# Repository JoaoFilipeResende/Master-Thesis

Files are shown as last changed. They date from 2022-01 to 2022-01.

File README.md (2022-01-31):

# Master Thesis Project
## Autonomous High-Resolution Image Acquisition System for Plankton

<p align="center">

</p>

### System Architecture

<p align="center">
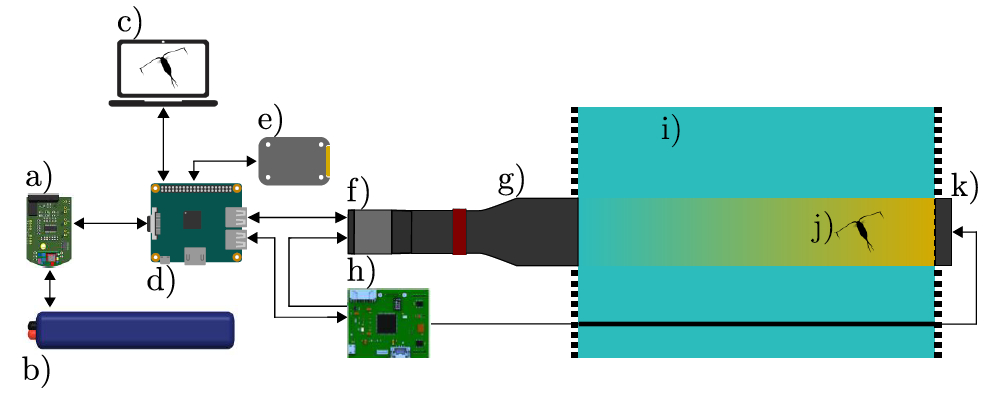
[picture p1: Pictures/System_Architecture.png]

</p>

a) BMS; b) Battery; c) External Connection; d) SBC; e) Storage; f) Camera; g) Optical lens; h) Illumination system control board; i) Water Column; j) Organism; k) LEDs.
   
### Mechanical Structure

<p align="center">
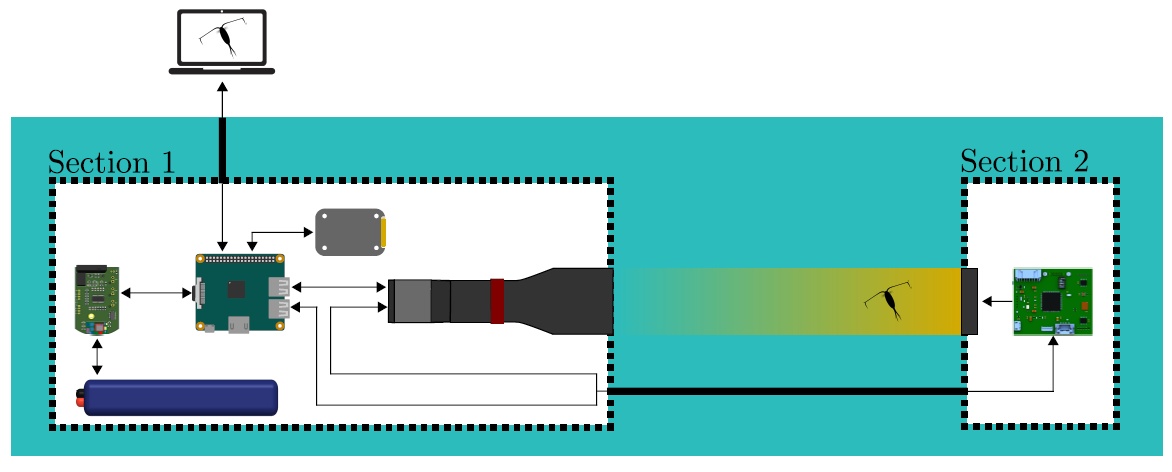
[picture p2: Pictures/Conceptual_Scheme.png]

</p>

### Hardware

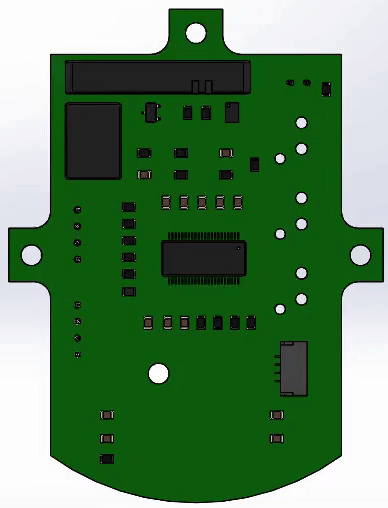
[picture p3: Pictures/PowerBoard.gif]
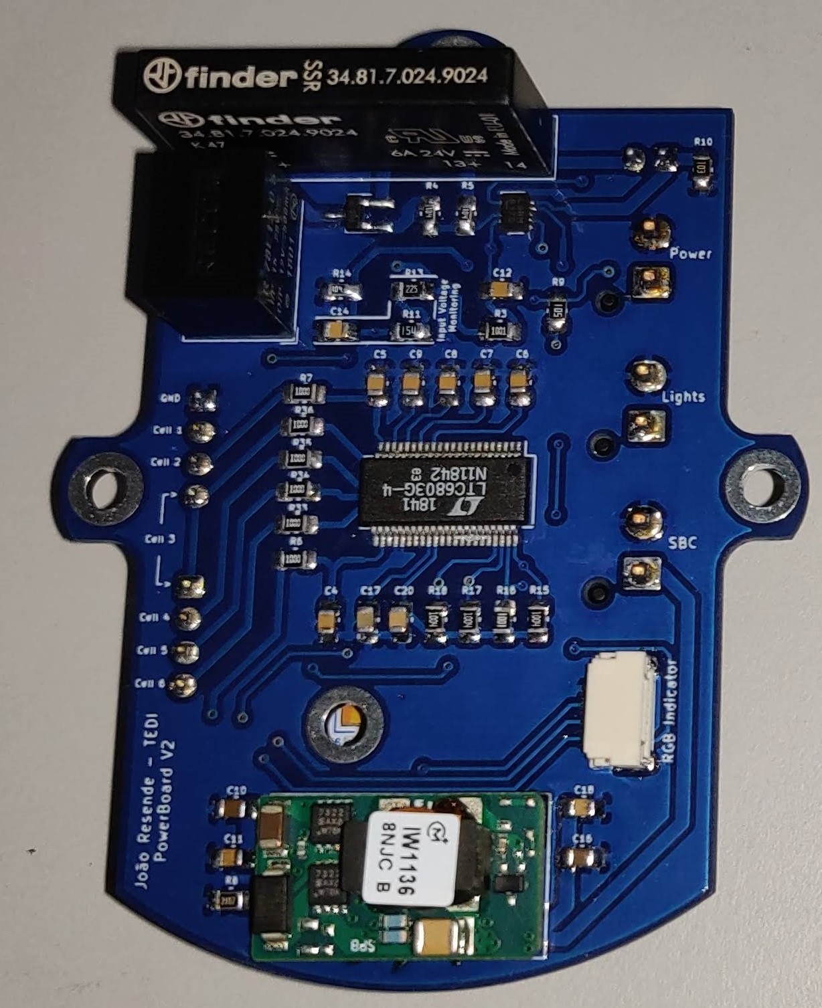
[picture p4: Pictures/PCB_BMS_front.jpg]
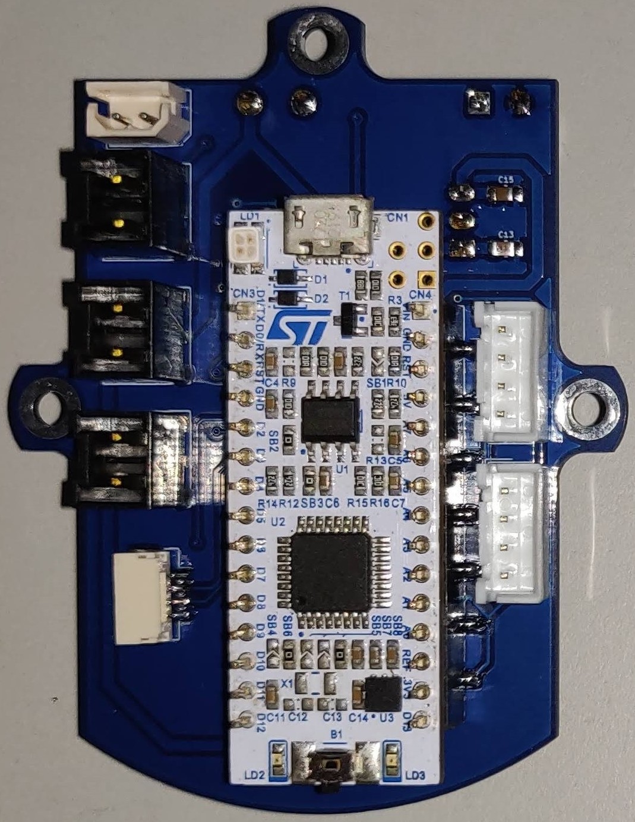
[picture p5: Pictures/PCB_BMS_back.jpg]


### Software

### Experimental Results

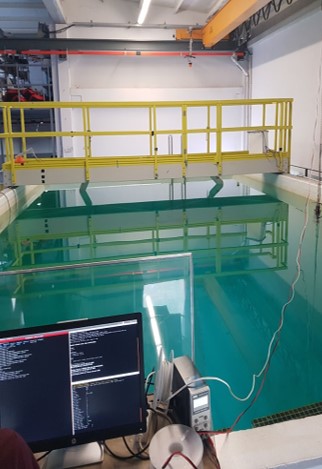
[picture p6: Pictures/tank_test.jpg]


<p align="center">
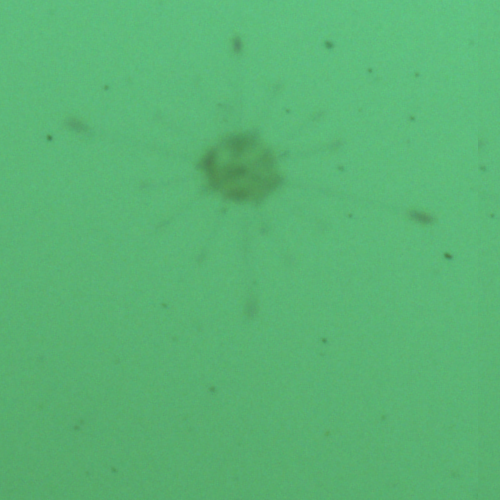
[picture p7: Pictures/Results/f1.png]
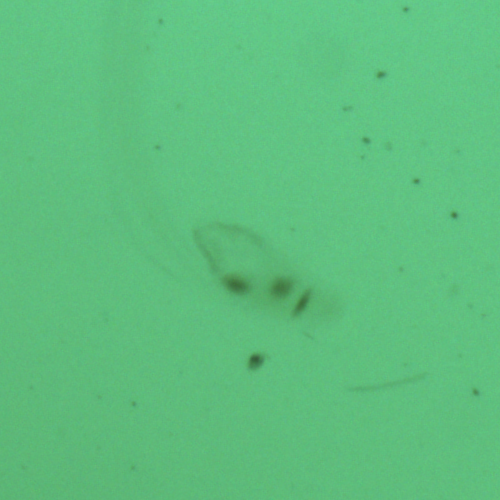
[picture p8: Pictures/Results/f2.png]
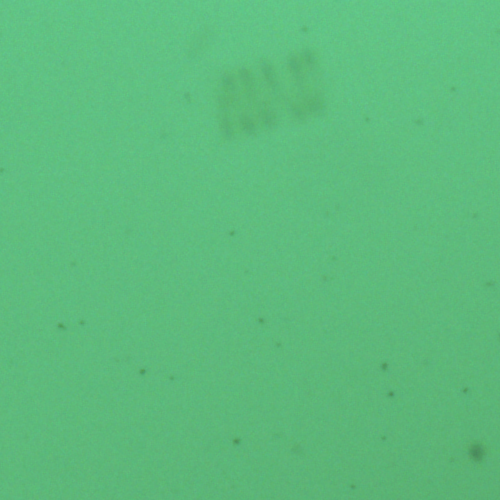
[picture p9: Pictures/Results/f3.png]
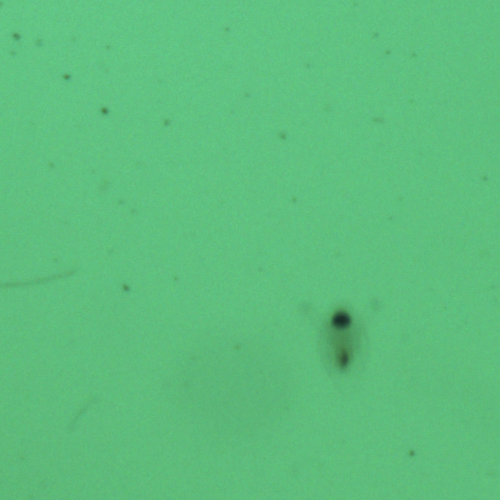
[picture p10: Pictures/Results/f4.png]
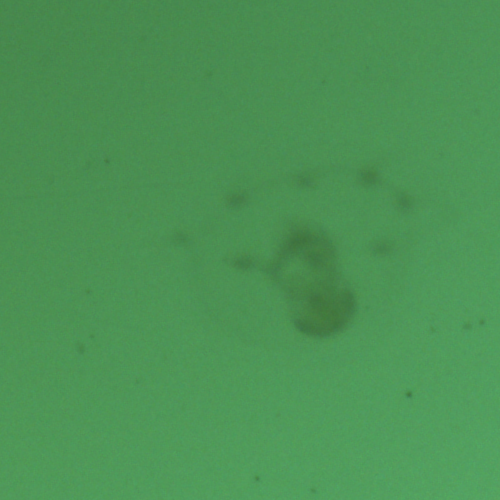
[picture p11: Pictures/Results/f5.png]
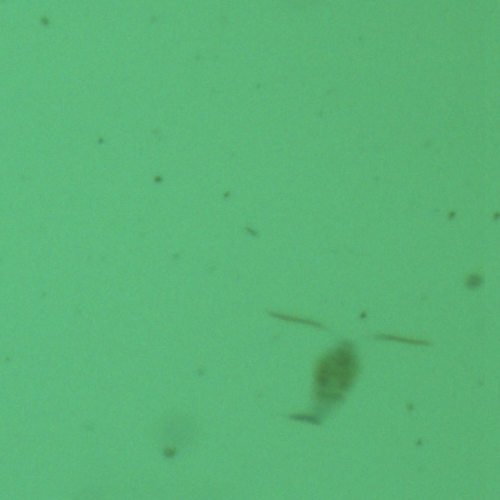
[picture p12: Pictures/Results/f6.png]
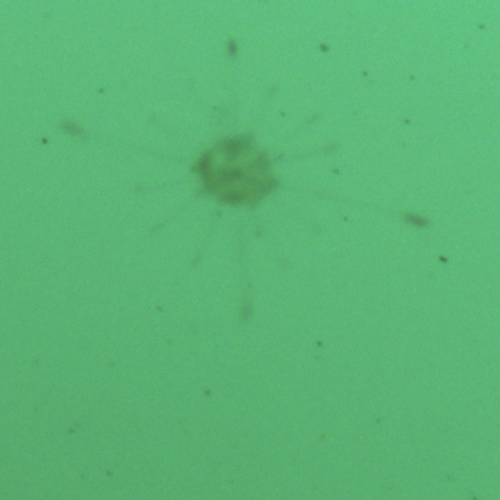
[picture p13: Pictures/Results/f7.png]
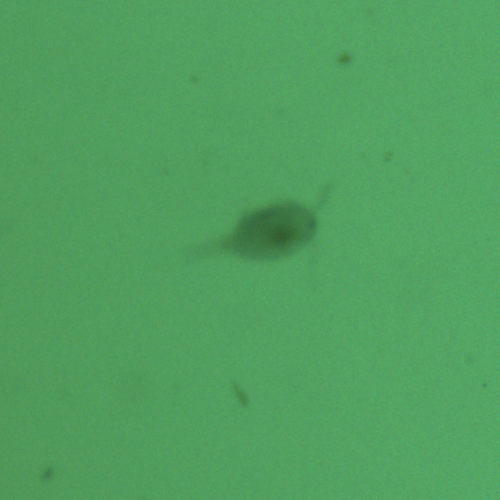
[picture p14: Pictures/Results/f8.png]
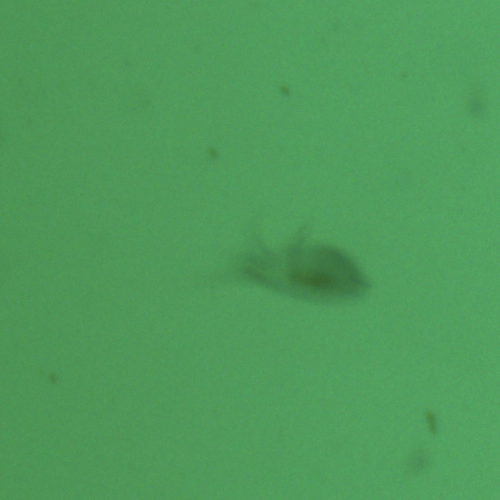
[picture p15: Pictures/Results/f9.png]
         
 </p>

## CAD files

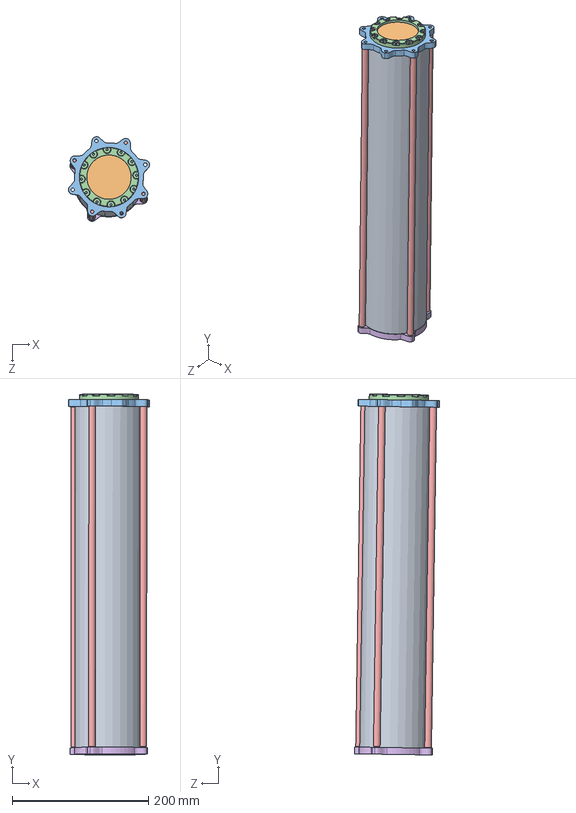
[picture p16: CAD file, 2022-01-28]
Mechanical Parts/assembly_camara.SLDASM
119.1 x 529.5 x 124.3 mm
cilider_camara
glass_camara_light
tampa_front1_camara_light
tampa_front2_camara_light
vara_suporte_camara x 4
tampa_back_camara

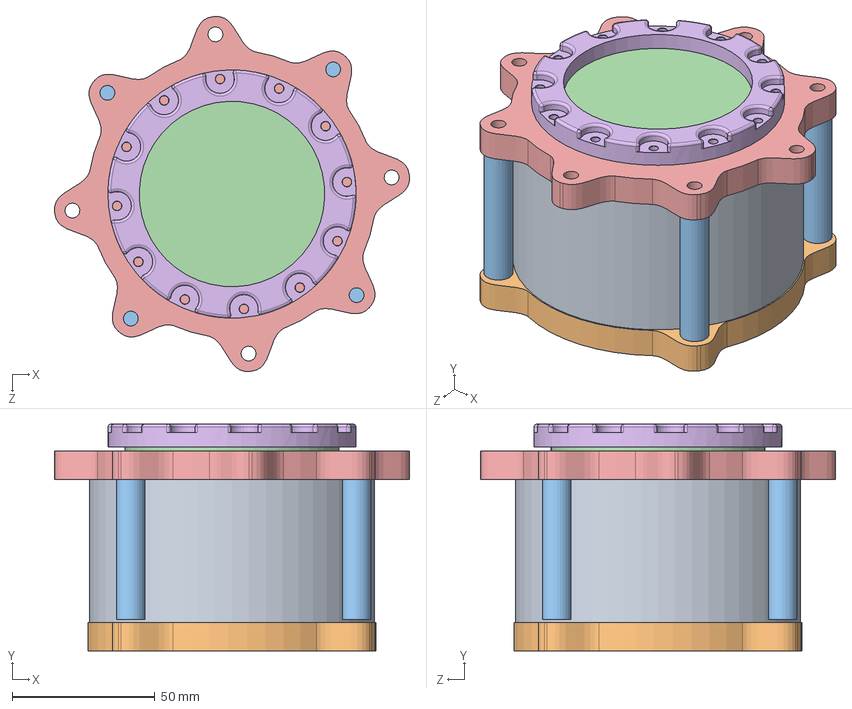
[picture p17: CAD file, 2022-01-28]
Mechanical Parts/assembly_light.SLDASM
124.4 x 79.5 x 124.4 mm
cilider_light
tampa_back_light
vara_suporte_light x 4
glass_camara_light
tampa_front1_camara_light
tampa_front2_camara_light

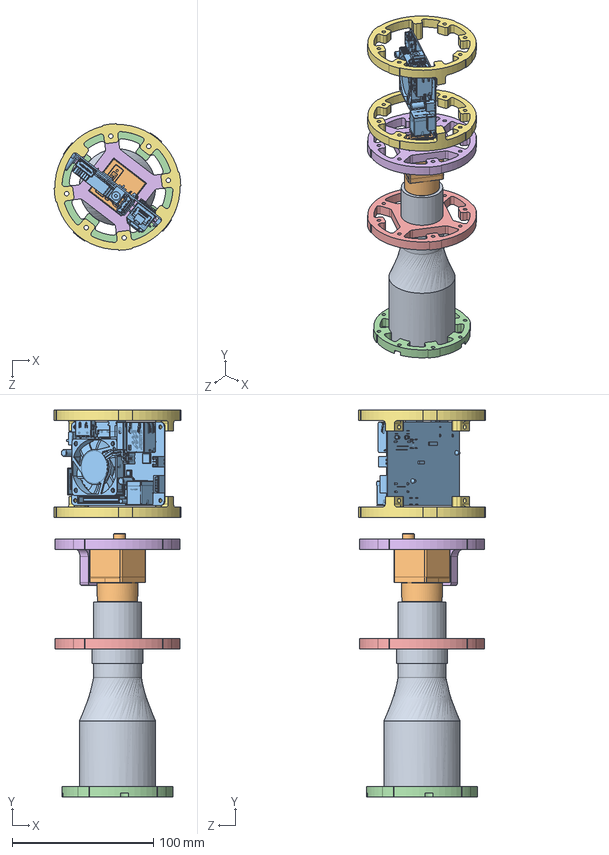
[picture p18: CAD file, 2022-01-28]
Mechanical Parts/assembly_internal.SLDASM
89.6 x 273.6 x 89.6 mm
DTCM230-36
IDS
Odroid-XU4
suporte_lente_meio
meio
camara
odroid x 2

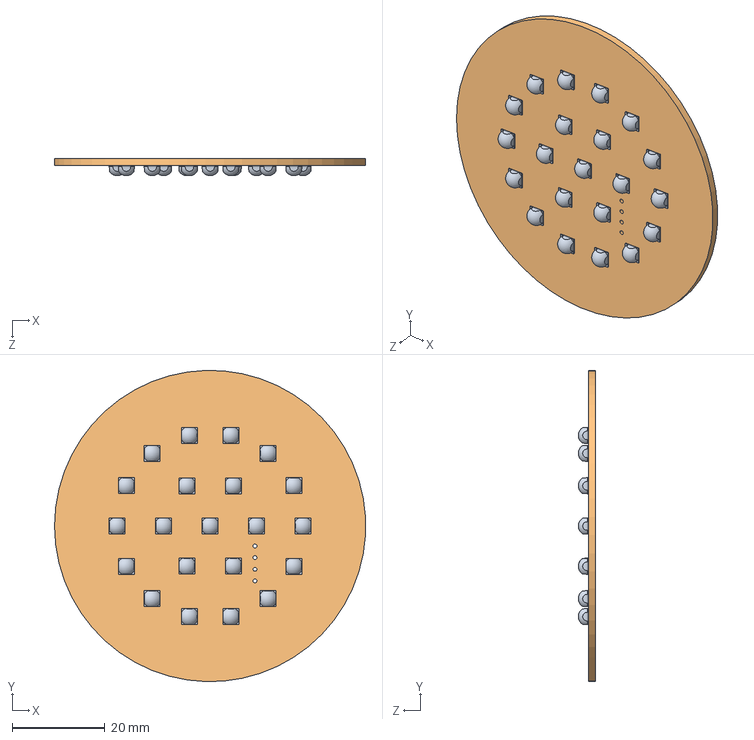
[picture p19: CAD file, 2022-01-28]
Mechanical Parts/Ligths.SLDASM
66.9 x 67.0 x 3.75 mm

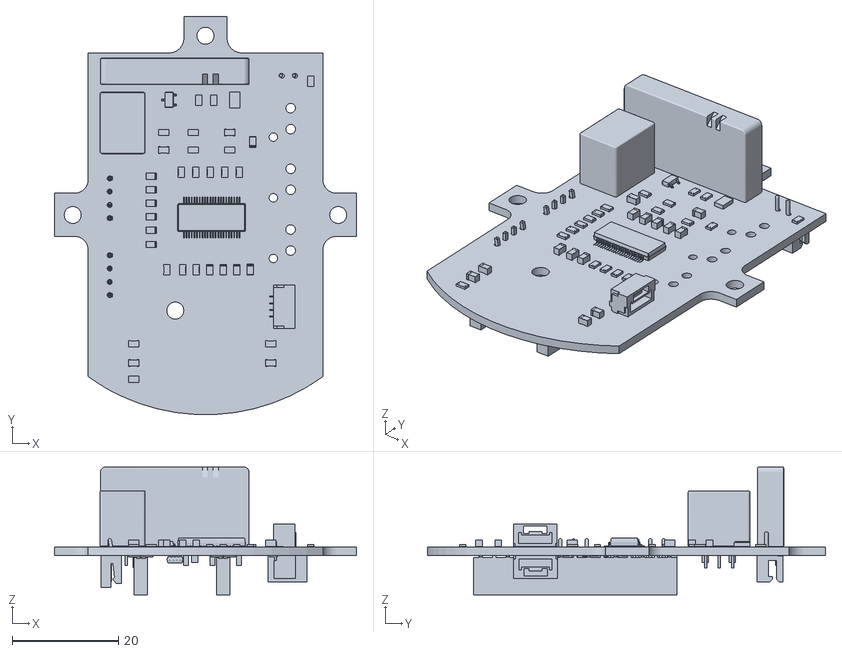
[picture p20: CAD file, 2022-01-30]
Hardware/PowerBoard/PowerBoard.STL
56.9 x 74.9 x 24.1

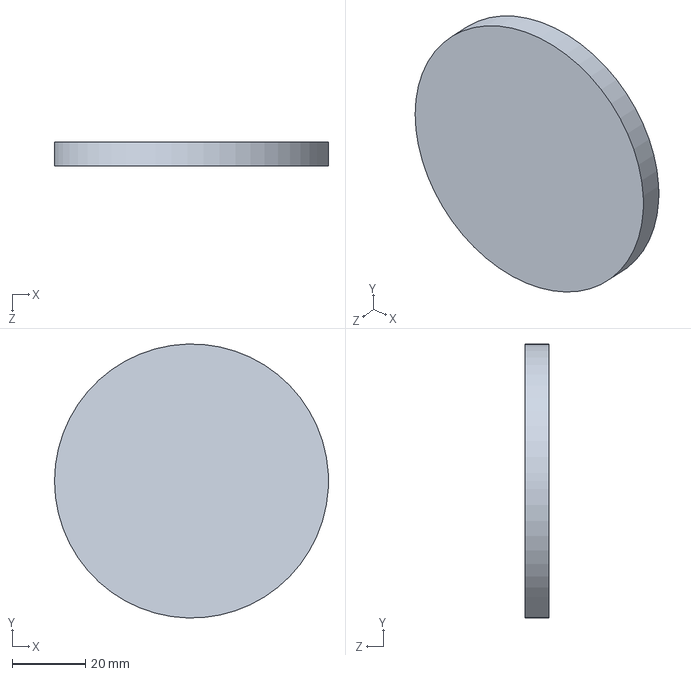
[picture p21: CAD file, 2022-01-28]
Mechanical Parts/glass_camara_light.SLDPRT
75.0 x 75.0 x 6.50 mm

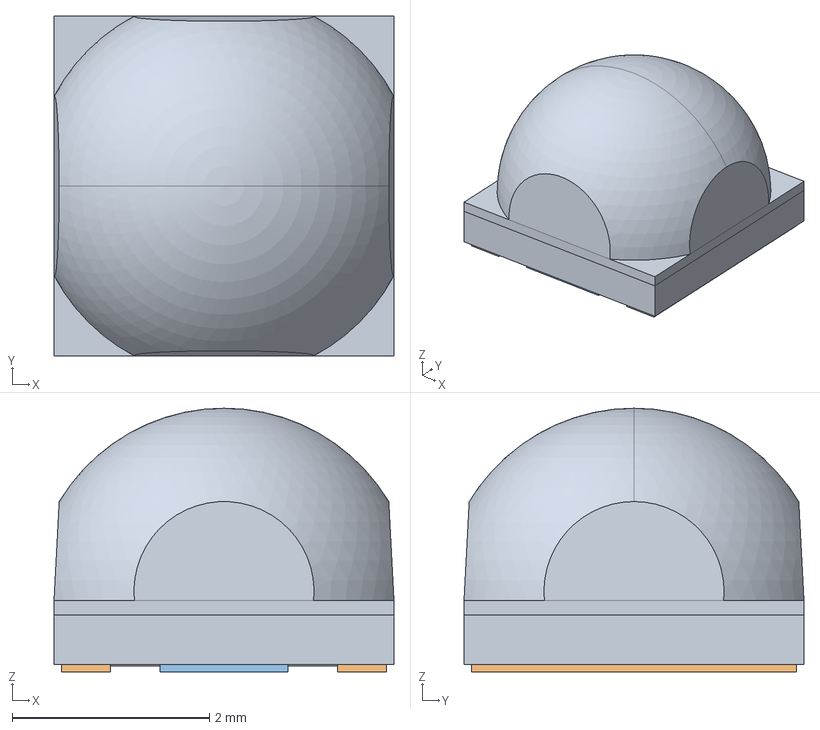
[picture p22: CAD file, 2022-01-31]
Hardware/LightsBoard/XPL_3D_STEP.stp
3.45 x 3.45 x 2.67 mm
2500-00341-BOTTOM-TRACE
2500-00341-SOLDERMASK-BACK
2500-00341-SOLDERMASK-BACK-N
2500-00341-TOP-TRACE
2500-00341-TOP-SOLDERMASK
1_95_TRUNCATED_DOME

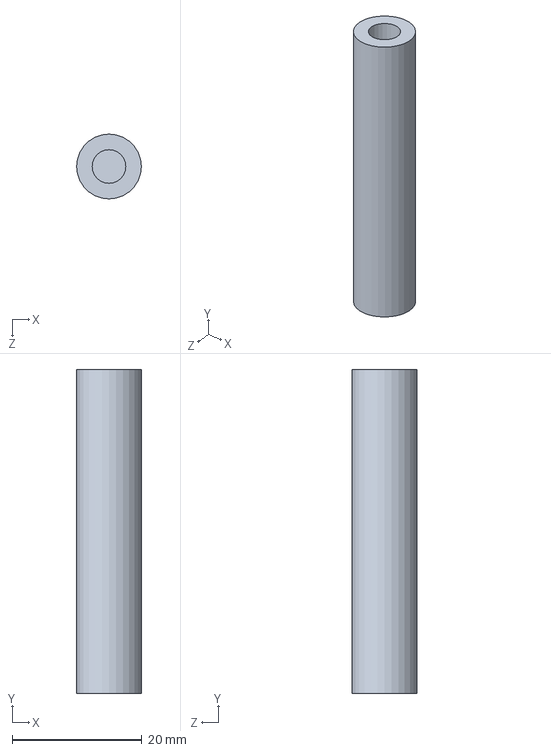
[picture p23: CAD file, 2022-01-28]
Mechanical Parts/vara_suporte_light.SLDPRT
10.0 x 50.0 x 10.0 mm

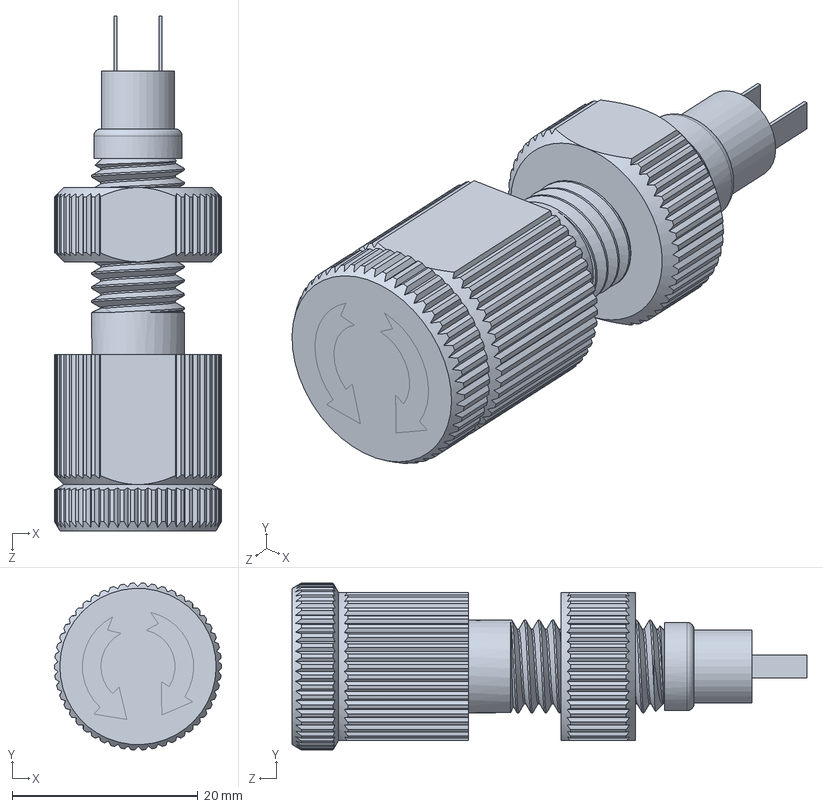
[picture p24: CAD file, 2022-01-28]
Mechanical Parts/SWITCH-10-5A-R1.SLDPRT
18.0 x 18.0 x 55.5 mm

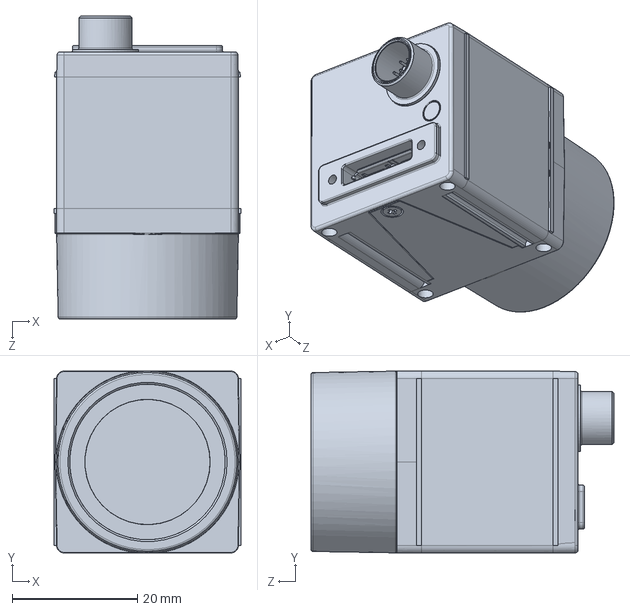
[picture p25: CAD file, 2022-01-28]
Mechanical Parts/IDS.SLDPRT
29.8 x 29.0 x 48.3 mm

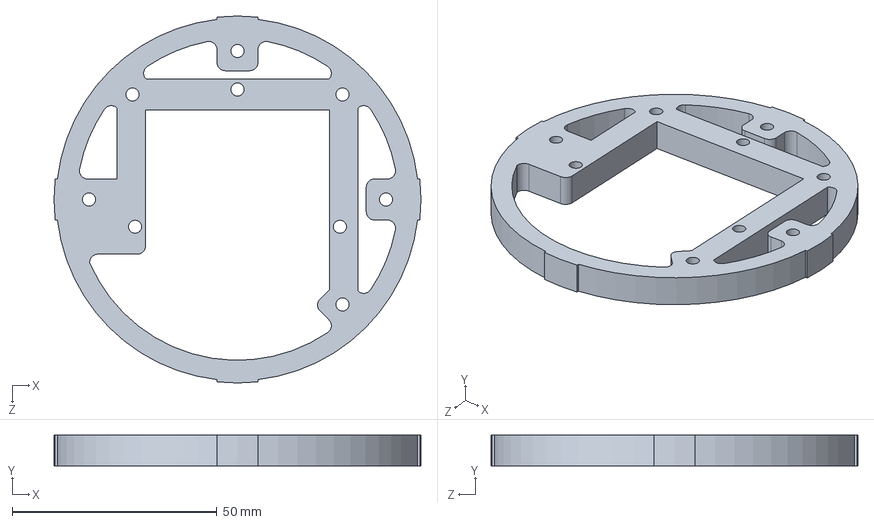
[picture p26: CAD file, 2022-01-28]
Mechanical Parts/pcb_support.SLDPRT
89.6 x 7.50 x 89.6 mm

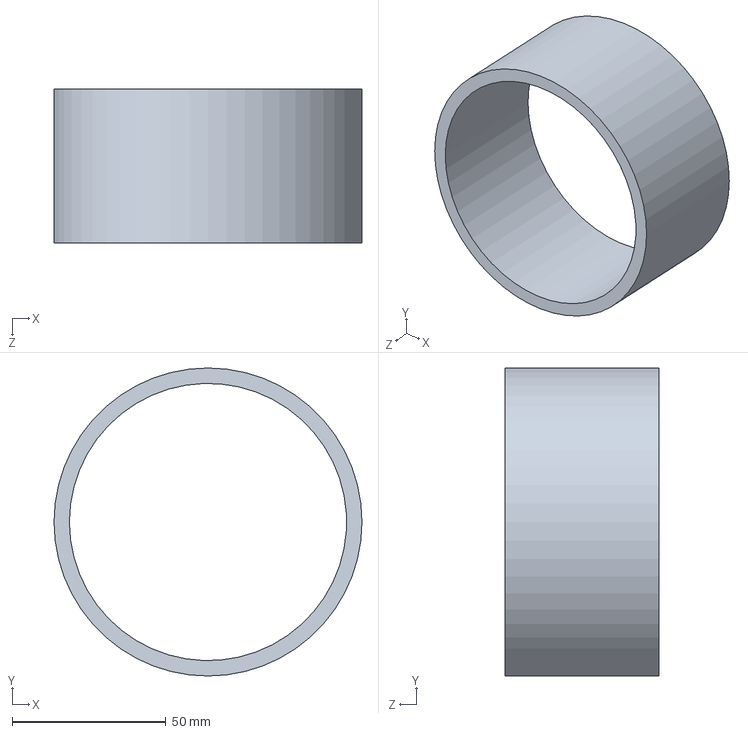
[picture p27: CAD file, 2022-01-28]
Mechanical Parts/cilider_light.SLDPRT
100.0 x 100.0 x 50.0 mm

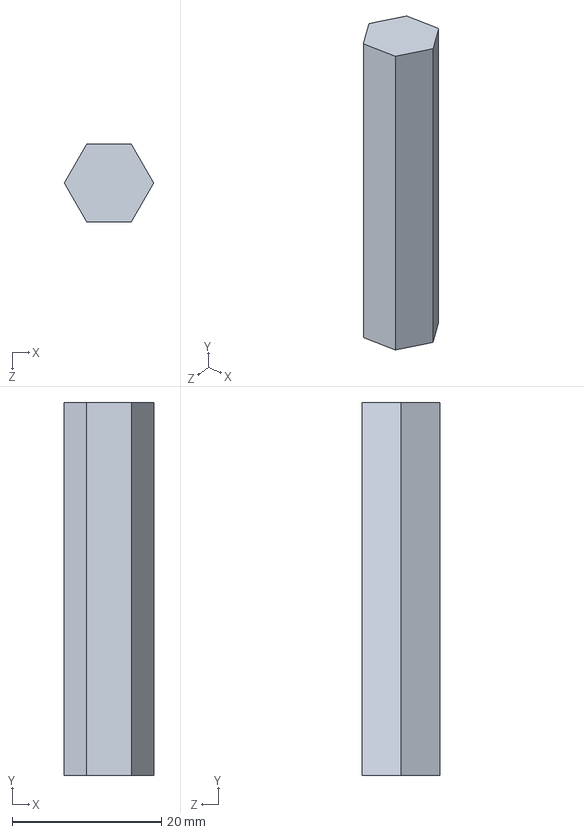
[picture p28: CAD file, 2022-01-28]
Mechanical Parts/espacador_7.SLDPRT
12.0 x 50.0 x 10.4 mm

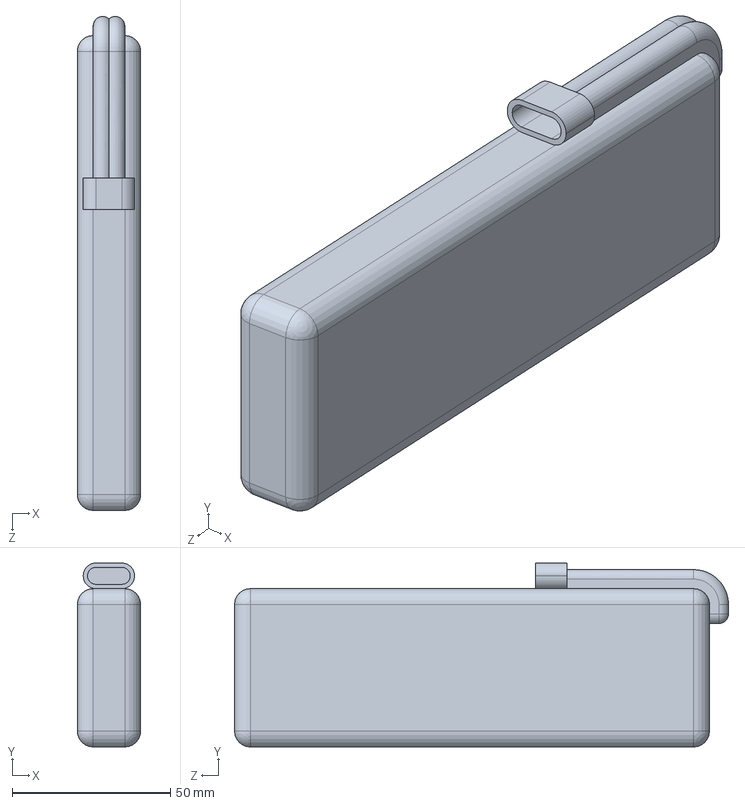
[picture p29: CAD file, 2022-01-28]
Mechanical Parts/battery2100.SLDPRT
20.0 x 58.1 x 156.0 mm

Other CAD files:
Mechanical Parts/XPL_3D_STEP.sldasm
Mechanical Parts/COMPOUND.sldprt
Mechanical Parts/cilider_camara.SLDPRT
Mechanical Parts/tampa_back_camara.SLDPRT
Hardware/LightsBoard/022057045.stp
Mechanical Parts/COMPOUND_3.sldprt
Mechanical Parts/DTCM230-36.SLDPRT
Mechanical Parts/PENETRATOR-M-BOLT-6MM-10-25-R2.SLDPRT
Mechanical Parts/PENETRATOR-M-NUT-10-8-R2.SLDPRT
Mechanical Parts/PowerBoard.SLDPRT
Mechanical Parts/battery_sup.SLDPRT
Mechanical Parts/camara.SLDPRT
Mechanical Parts/espacador.SLDPRT
Mechanical Parts/espacador_2.SLDPRT
Mechanical Parts/espacador_3.SLDPRT
Mechanical Parts/espacador_4.SLDPRT
Mechanical Parts/espacador_5.SLDPRT
Mechanical Parts/espacador_6.SLDPRT
Mechanical Parts/mcbh8f-wb.SLDPRT
Mechanical Parts/mcbh8m-wb.SLDPRT
Mechanical Parts/meio.SLDPRT
Mechanical Parts/odroid.SLDPRT
Mechanical Parts/suporte_lente_meio.SLDPRT
Mechanical Parts/tampa_back_light.SLDPRT
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

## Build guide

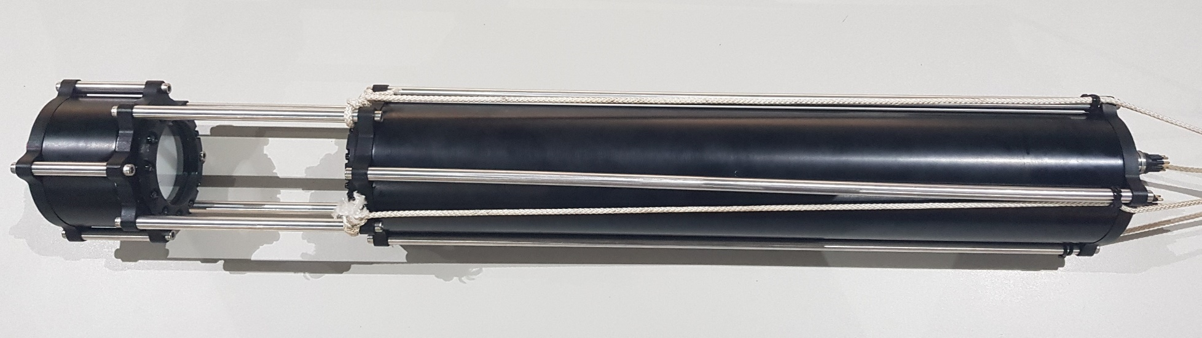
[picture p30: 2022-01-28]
Pictures/final_assembly_2.png

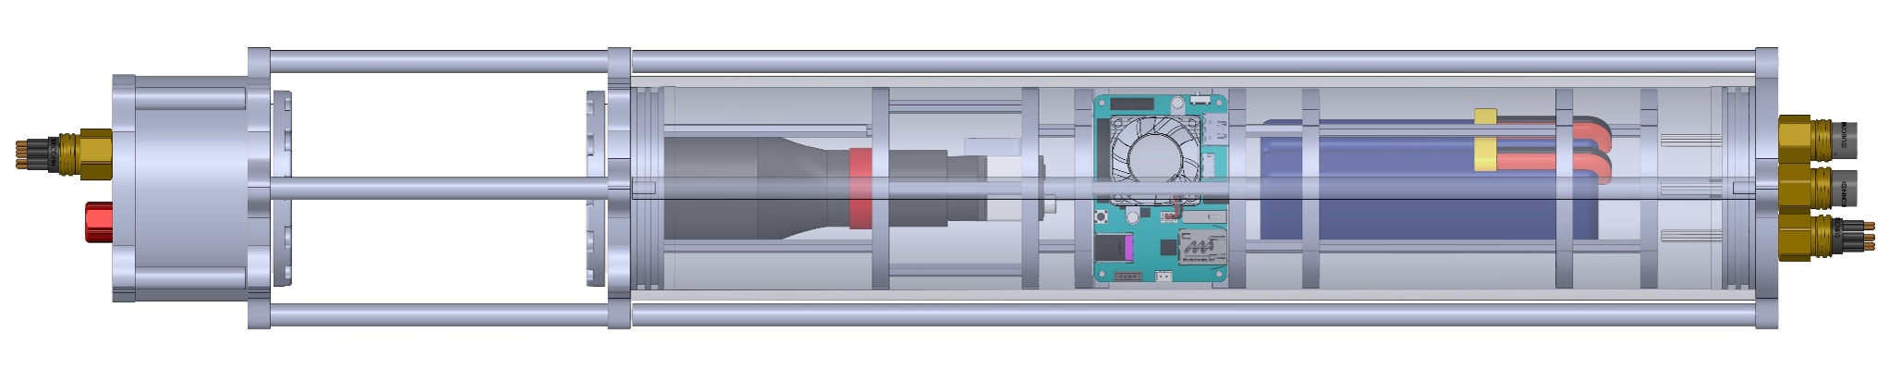
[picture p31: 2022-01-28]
Pictures/final_assembly.png

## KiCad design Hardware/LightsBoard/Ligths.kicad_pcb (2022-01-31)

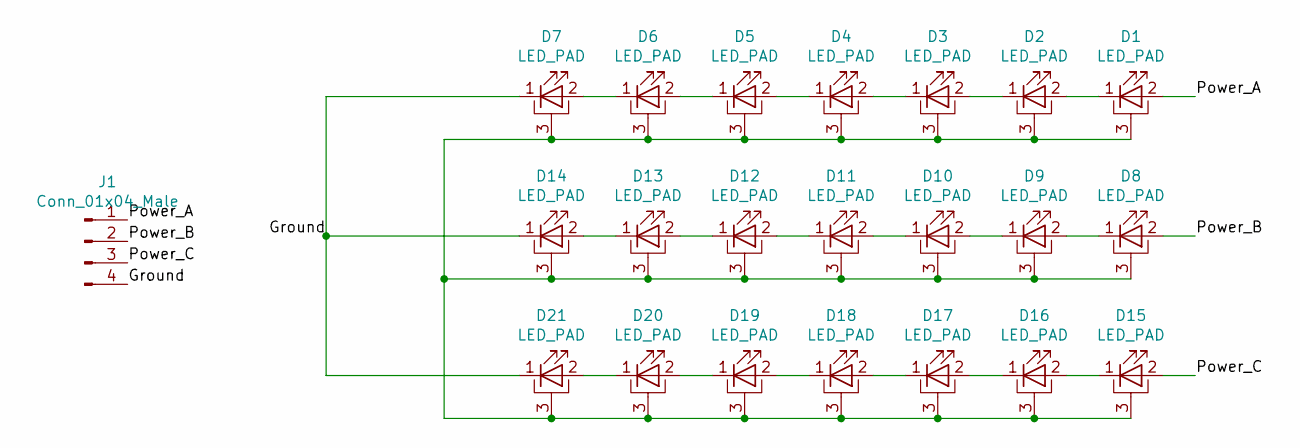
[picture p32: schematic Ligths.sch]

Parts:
D1, D2, D3, D4, D5, D6, D7, D8, D9, D10, D11, D12, D13, D14, D15, D16, D17, D18, D19, D20, D21: LED_PAD; LED_Cree-XP
J1: Conn_01x04_Male; Molex_SPOX_5267-04A_1x04_P2.50mm_Vertical

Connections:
/Ground: D7.1 (K), D14.1 (K), D21.1 (K), J1.4
/Power_A: D1.2 (A), J1.1
/Power_B: D8.2 (A), J1.2
/Power_C: D15.2 (A), J1.3
unnamed: D1.1 (K), D2.2 (A)
unnamed: D1.3 (PAD), D2.3 (PAD), D3.3 (PAD), D4.3 (PAD), D5.3 (PAD), D6.3 (PAD), D7.3 (PAD), D8.3 (PAD), D9.3 (PAD), D10.3 (PAD), D11.3 (PAD), D12.3 (PAD), D13.3 (PAD), D14.3 (PAD), D15.3 (PAD), D16.3 (PAD), D17.3 (PAD), D18.3 (PAD), D19.3 (PAD), D20.3 (PAD), D21.3 (PAD)
unnamed: D2.1 (K), D3.2 (A)
unnamed: D3.1 (K), D4.2 (A)
unnamed: D4.1 (K), D5.2 (A)
unnamed: D5.1 (K), D6.2 (A)
unnamed: D6.1 (K), D7.2 (A)
unnamed: D8.1 (K), D9.2 (A)
unnamed: D10.1 (K), D11.2 (A)
unnamed: D9.1 (K), D10.2 (A)
unnamed: D11.1 (K), D12.2 (A)
unnamed: D12.1 (K), D13.2 (A)
unnamed: D13.1 (K), D14.2 (A)
unnamed: D15.1 (K), D16.2 (A)
unnamed: D16.1 (K), D17.2 (A)
unnamed: D17.1 (K), D18.2 (A)
unnamed: D18.1 (K), D19.2 (A)
unnamed: D19.1 (K), D20.2 (A)
unnamed: D20.1 (K), D21.2 (A)

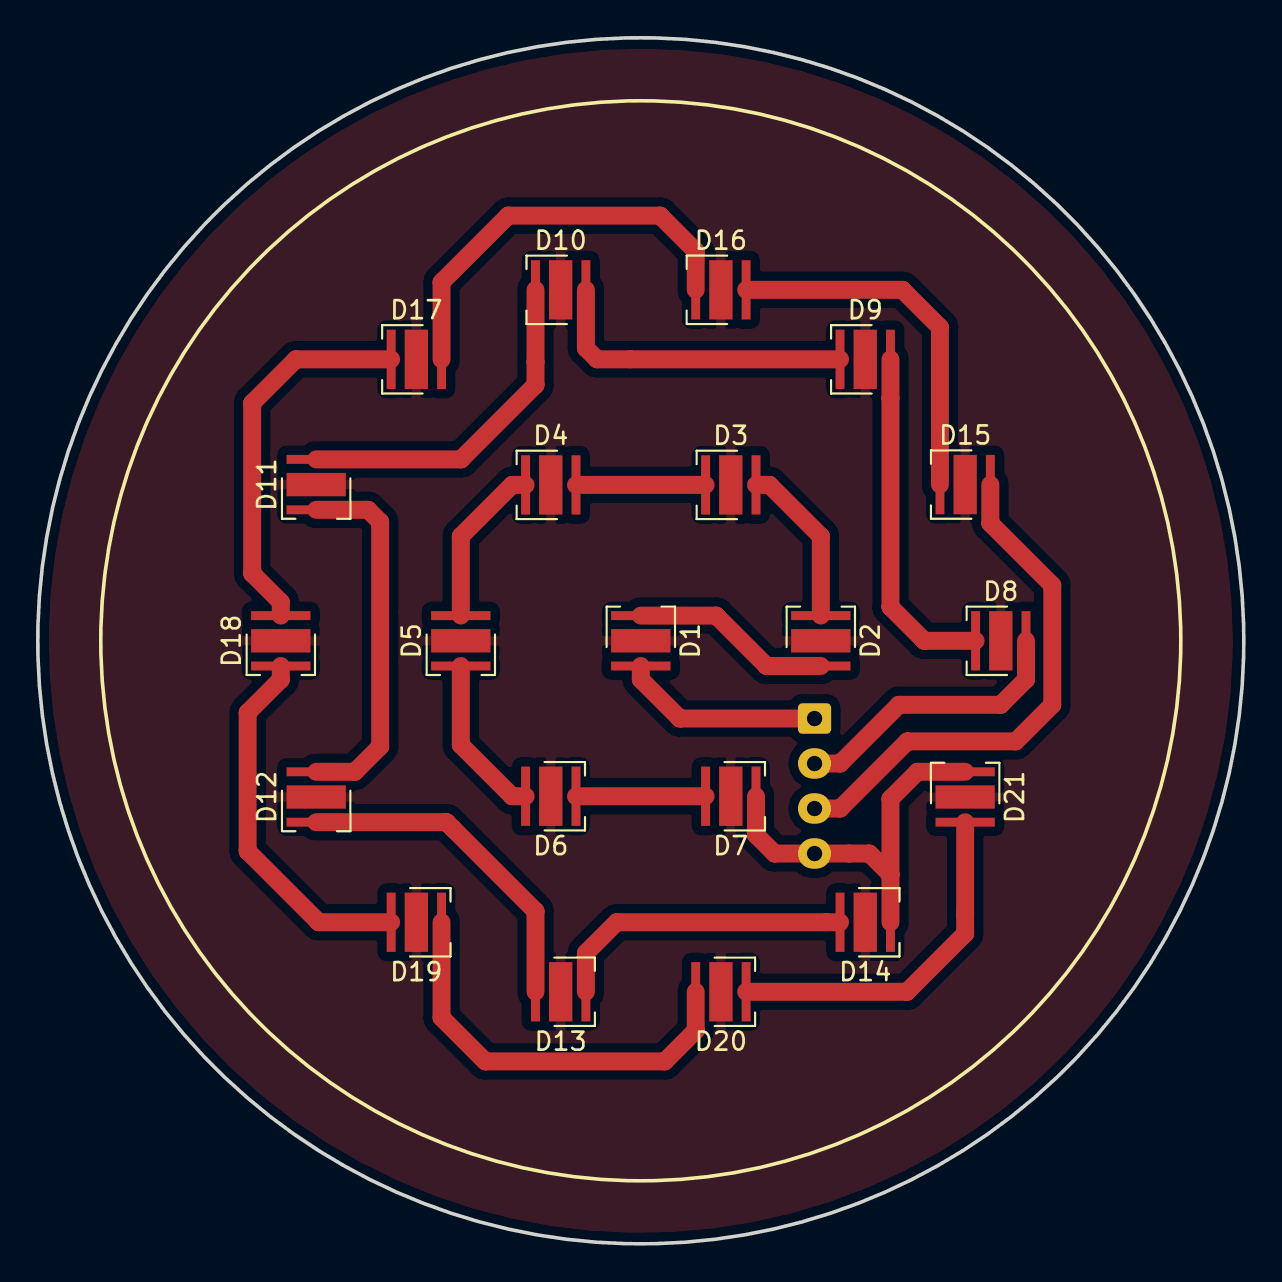
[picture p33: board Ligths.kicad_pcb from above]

Board: 2 copper layers, 67.0 x 67.0 mm, 22 parts (1 on the bottom side), 23 nets.

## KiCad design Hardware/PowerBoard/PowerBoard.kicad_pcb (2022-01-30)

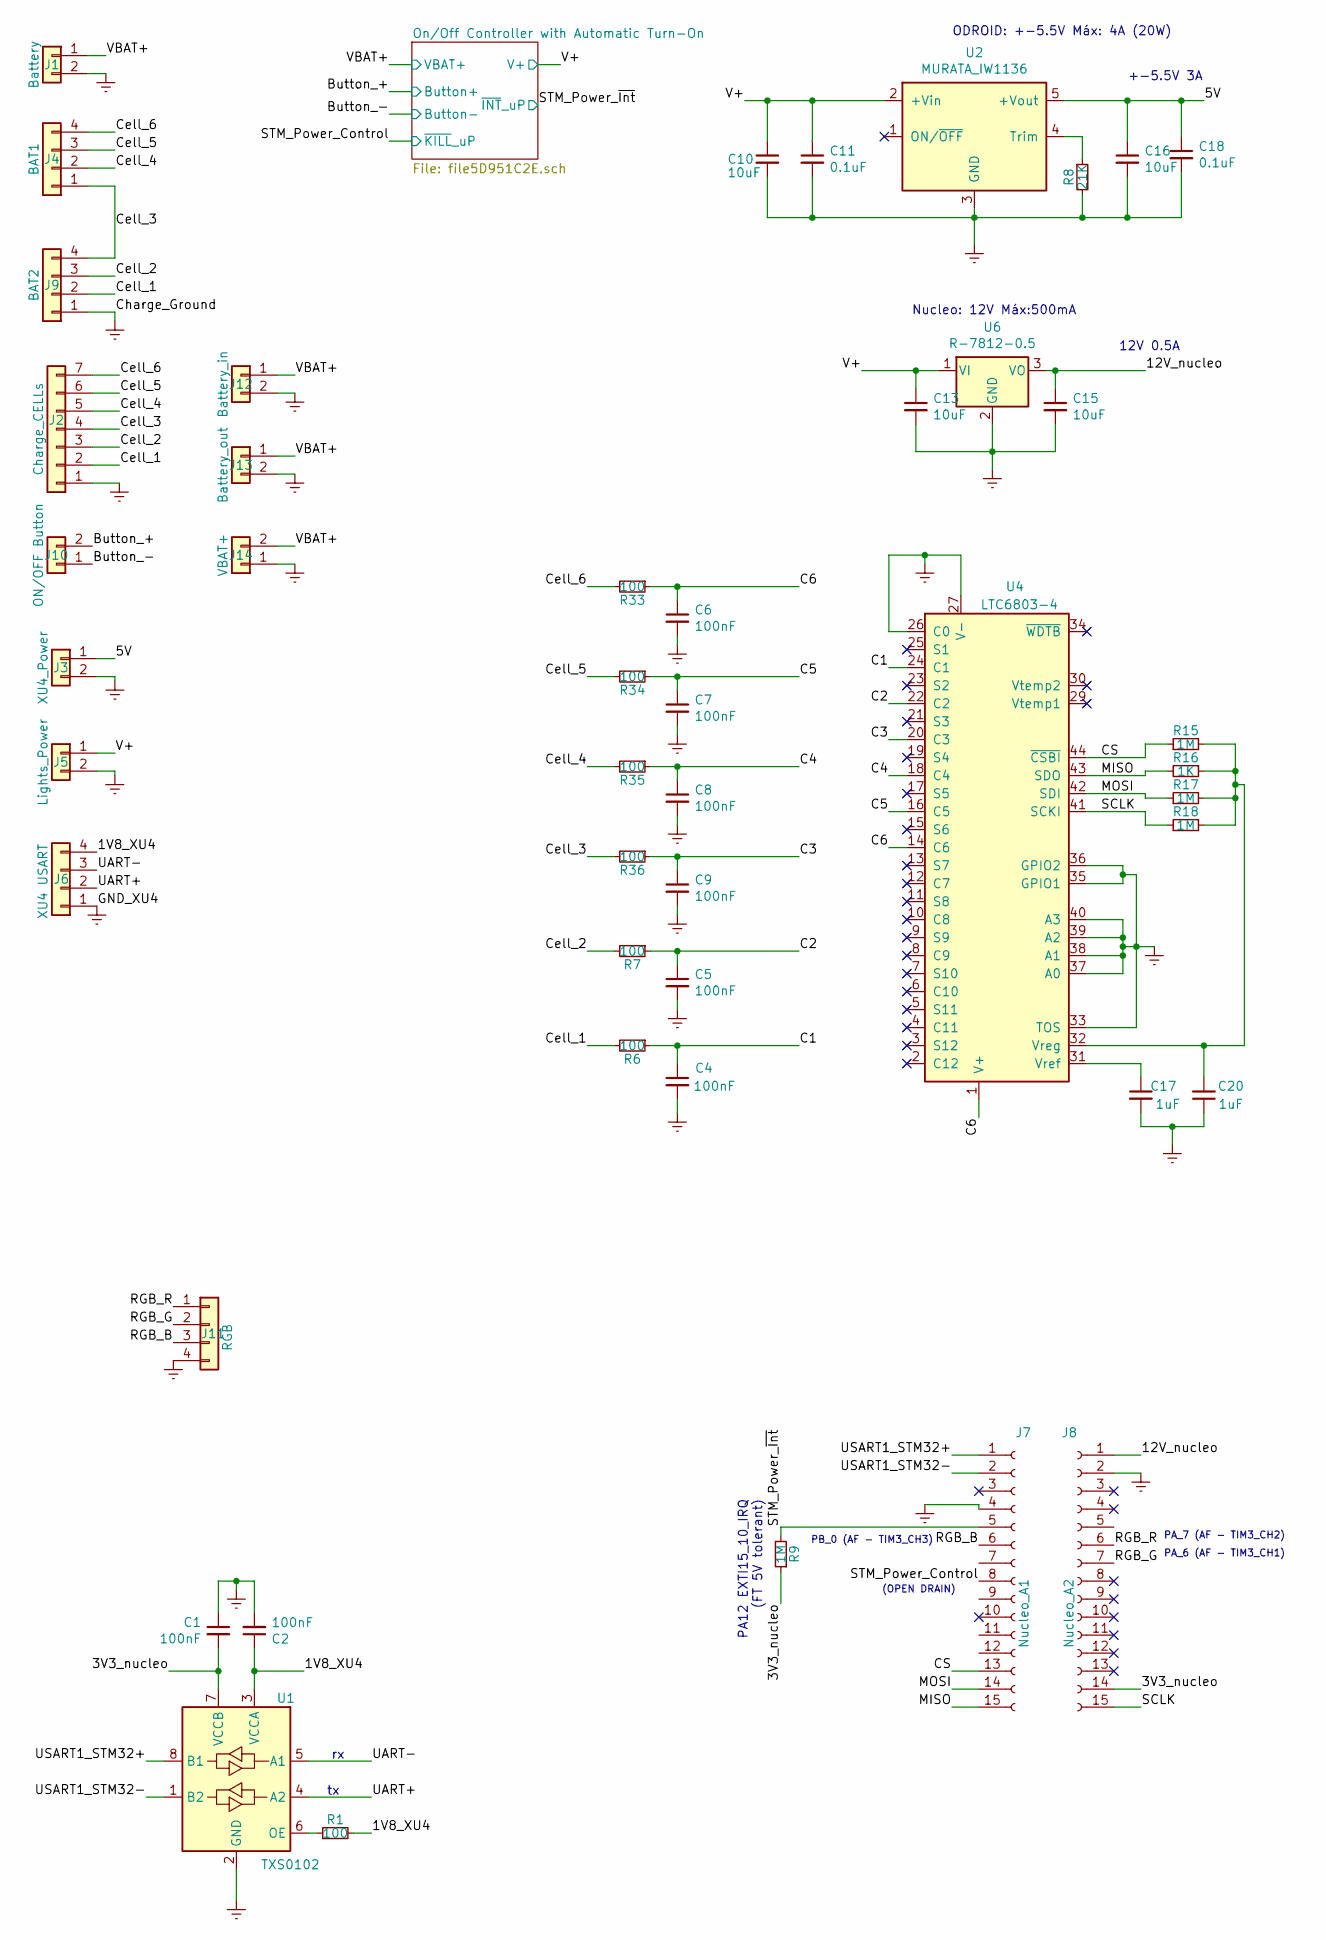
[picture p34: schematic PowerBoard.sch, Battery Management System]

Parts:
C1, C2, C4, C5, C6, C7, C8, C9: 100nF; C_0805_2012Metric_Pad1.15x1.40mm_HandSolder
C10, C13, C15, C16: 10uF; C_0805_2012Metric_Pad1.15x1.40mm_HandSolder
C11, C18: 0.1uF; C_0805_2012Metric_Pad1.15x1.40mm_HandSolder
C17, C20: 1uF; C_0805_2012Metric_Pad1.15x1.40mm_HandSolder
J1: Battery; Hirose_DF63-2P-3.96DSA_1x02_P3.96mm_Horizontal
J2: Charge_CELLs; JST_EH_B07B-EH-A_1x07_P2.50mm_Vertical
J3: XU4_Power; Hirose_DF63-2P-3.96DSA_1x02_P3.96mm_Horizontal
J4: BAT1; JST_EH_B04B-EH-A_1x04_P2.50mm_Vertical
J5: Lights_Power; Hirose_DF63-2P-3.96DSA_1x02_P3.96mm_Horizontal
J6: XU4 USART; JST_GH_SM04B-GHS-TB_1x04-1MP_P1.25mm_Horizontal
J7: Nucleo_A1; PinSocket_1x15_P2.54mm_Vertical_SMD_Pin1Left
J8: Nucleo_A2; PinSocket_1x15_P2.54mm_Vertical_SMD_Pin1Left
J9: BAT2; JST_EH_B04B-EH-A_1x04_P2.50mm_Vertical
J10: ON/OFF Button; Molex_SPOX_5267-02A_1x02_P2.50mm_Vertical
J11: RGB; JST_GH_SM04B-GHS-TB_1x04-1MP_P1.25mm_Horizontal
J12: Battery_in; Hirose_DF63-2P-3.96DSA_1x02_P3.96mm_Horizontal
J13: Battery_out; Hirose_DF63-2P-3.96DSA_1x02_P3.96mm_Horizontal
J14: VBAT+; Molex_SPOX_5267-02A_1x02_P2.50mm_Vertical
R1, R6, R7, R33, R34, R35, R36: 100; R_0805_2012Metric_Pad1.15x1.40mm_HandSolder
R8: 21K; R_0805_2012Metric_Pad1.15x1.40mm_HandSolder
R9, R15, R17, R18: 1M; R_0805_2012Metric_Pad1.15x1.40mm_HandSolder
R16: 1K; R_0805_2012Metric_Pad1.15x1.40mm_HandSolder
U1: TXS0102; VSSOP-8_3.0x3.0mm_P0.65mm
U2: MURATA_IW1136; IW1136
U4: LTC6803-4; SSOP-44_5.3x12.8mm_P0.5mm
U6: R-7812-0.5; Converter_DCDC_RECOM_R-78E-0.5_THT

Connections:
/1V8_XU4: C2.1, J6.4, R1.2, U1.3 (VCCA)
/3V3_nucleo: C1.2, J8.14, R9.1, U1.7 (VCCB)
/5V: C16.1, C18.1, J3.1, U2.5 (+Vout)
/12V_nucleo: C15.1, J8.1, U6.3 (VO)
/Button_+: J1.1, J10.2, J12.1, J13.1, J14.2; also elsewhere on the board
/Button_-: J10.1; also elsewhere on the board
/C1: C4.1, R6.1, U4.24 (C1)
/C2: C5.1, R7.1, U4.22 (C2)
/C3: C9.1, R36.1, U4.20 (C3)
/C4: C8.1, R35.1, U4.18 (C4)
/C5: C7.1, R34.1, U4.16 (C5)
/C6: C6.1, R33.1, U4.1 (V+), U4.14 (C6)
/CS: J7.13, R15.1, U4.44 (~CSBI~)
/Cell_1: J2.2, J9.2, R6.2
/Cell_2: J2.3, J9.3, R7.2
/Cell_3: J2.4, J4.1, J9.4, R36.2
/Cell_4: J2.5, J4.2, R35.2
/Cell_5: J2.6, J4.3, R34.2
/Cell_6: J2.7, J4.4, R33.2
/MISO: J7.15, R16.2, U4.43 (SDO)
/MOSI: J7.14, R17.1, U4.42 (SDI)
/RGB_B: J7.6, J11.3
/RGB_G: J8.7, J11.2
/RGB_R: J8.6, J11.1
/SCLK: J8.15, R18.1, U4.41 (SCKI)
/STM_Power_Control: J7.8; also elsewhere on the board
/STM_Power_~Int~: J7.5, R9.2; also elsewhere on the board
/UART+: J6.2, U1.4 (A2)
/UART-: J6.3, U1.5 (A1)
/USART1_STM32+: J7.1, U1.8 (B1)
/USART1_STM32-: J7.2, U1.1 (B2)
/V+: C10.1, C11.1, C13.1, J5.1, U2.2 (+Vin), U6.1 (VI); also elsewhere on the board
Earth: C1.1, C2.2, C4.2, C5.2, C6.2, C7.2, C8.2, C9.2, C10.2, C11.2, C13.2, C15.2, C16.2, C17.2, C18.2, C20.1, J1.2, J2.1, J3.2, J5.2, J6.1, J7.4, J8.2, J9.1, J11.4, J12.2, J13.2, J14.1, R8.2, U1.2 (GND), U2.3 (GND), U4.26 (C0), U4.27 (V-), U4.33 (TOS), U4.35 (GPIO1), U4.36 (GPIO2), U4.37 (A0), U4.38 (A1), U4.39 (A2), U4.40 (A3), U6.2 (GND); also elsewhere on the board
unnamed: C17.1, U4.31 (Vref)
unnamed: C20.2, R15.2, R16.1, R17.2, R18.2, U4.32 (Vreg)
unnamed: R1.1, U1.6 (OE)
unnamed: R8.1, U2.4 (Trim)

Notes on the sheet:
ODROID: +-5.5V Máx: 4A (20W)
Nucleo: 12V Máx:500mA
12V 0.5A
+-5.5V 3A
PB_0 (AF - TIM3_CH3)
PA_7 (AF - TIM3_CH2)
PA_6 (AF - TIM3_CH1)
PA12 EXTI15_10_IRQ (FT 5V tolerant)
(OPEN DRAIN)

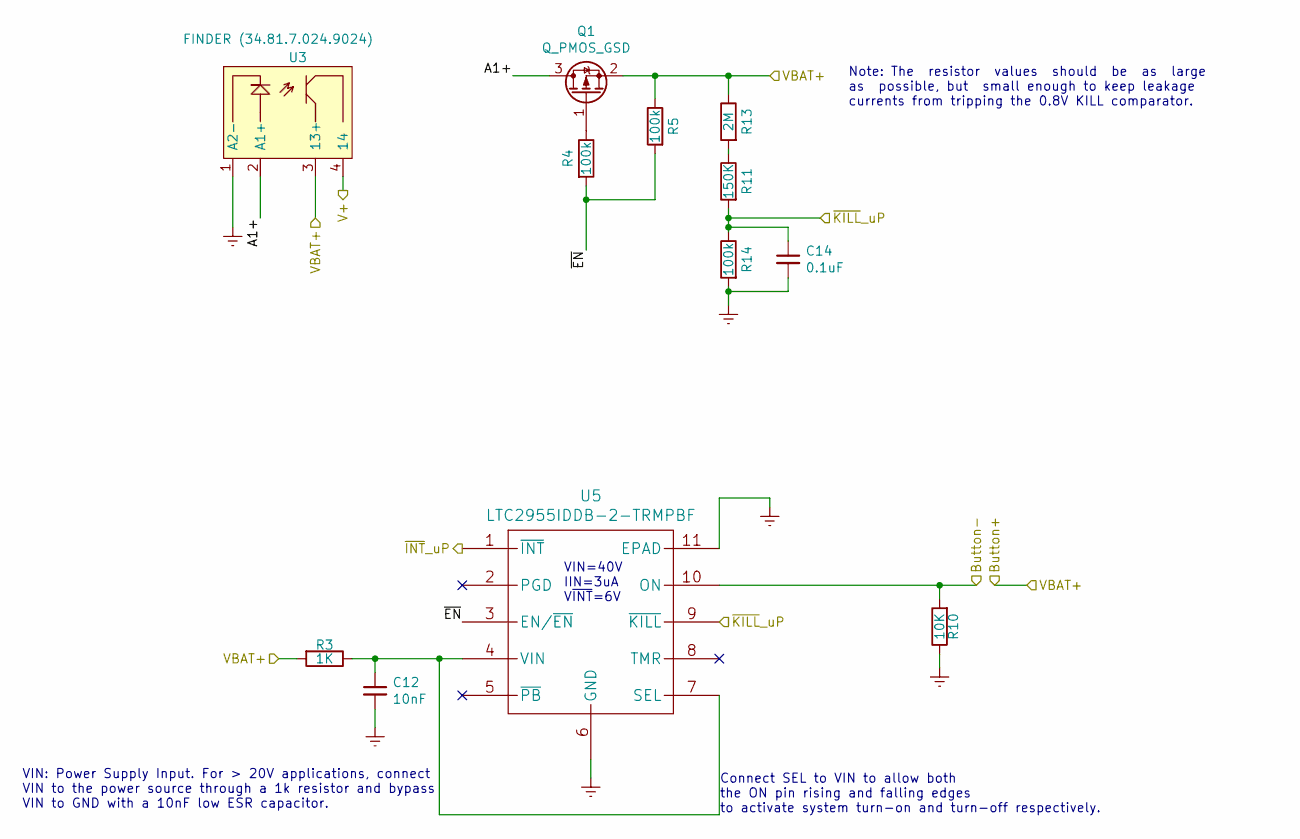
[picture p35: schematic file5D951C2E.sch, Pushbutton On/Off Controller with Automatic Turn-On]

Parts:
C12: 10nF; C_0805_2012Metric_Pad1.15x1.40mm_HandSolder
C14: 0.1uF; C_0805_2012Metric_Pad1.15x1.40mm_HandSolder
Q1: Q_PMOS_GSD; TSOT-23_HandSoldering
R3: 1K; R_0805_2012Metric_Pad1.15x1.40mm_HandSolder
R4, R5, R14: 100k; R_0805_2012Metric_Pad1.15x1.40mm_HandSolder
R10: 10K; R_0805_2012Metric_Pad1.15x1.40mm_HandSolder
R11: 150K; R_0805_2012Metric_Pad1.15x1.40mm_HandSolder
R13: 2M; R_0805_2012Metric_Pad1.15x1.40mm_HandSolder
U3: FINDER (34.81.7.024.9024); Relay_SPDT_Finder_34.81_Vertical
U5: LTC2955IDDB-2-TRMPBF; DFN-10-1EP_2x3mm_P0.5mm_EP0.64x2.4mm

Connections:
/Button_+: Q1.2 (S), R3.2, R5.1, R13.1, U3.3 (13+); also elsewhere on the board
/Button_-: R10.2, U5.10 (ON); also elsewhere on the board
/On/Off Controller with Automatic Turn-On/A1+: Q1.3 (D), U3.2 (A1+)
/On/Off Controller with Automatic Turn-On/~EN: R4.2, R5.2, U5.3 (EN/~EN)
/STM_Power_Control: C14.1, R11.2, R14.1, U5.9 (~KILL); also elsewhere on the board
/STM_Power_~Int~: U5.1 (~INT); also elsewhere on the board
/V+: U3.4 (14); also elsewhere on the board
Earth: C12.2, C14.2, R10.1, R14.2, U3.1 (A2-), U5.6 (GND), U5.11 (EPAD); also elsewhere on the board
unnamed: C12.1, R3.1, U5.4 (VIN), U5.7 (SEL)
unnamed: Q1.1 (G), R4.1
unnamed: R11.1, R13.2

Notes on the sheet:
VIN=40V IIN=3uA V~INT~=6V
Note: The resistor values should be as large as possible, but small enough to keep leakage currents from tripping the 0.8V KILL comparator.
VIN: Power Supply Input. For > 20V applications, connect VIN to the power source through a 1k resistor and bypass VIN to GND with a 10nF low ESR capacitor.
Connect SEL to VIN to allow both the ON pin rising and falling edges to activate system turn-on and turn-off respectively.

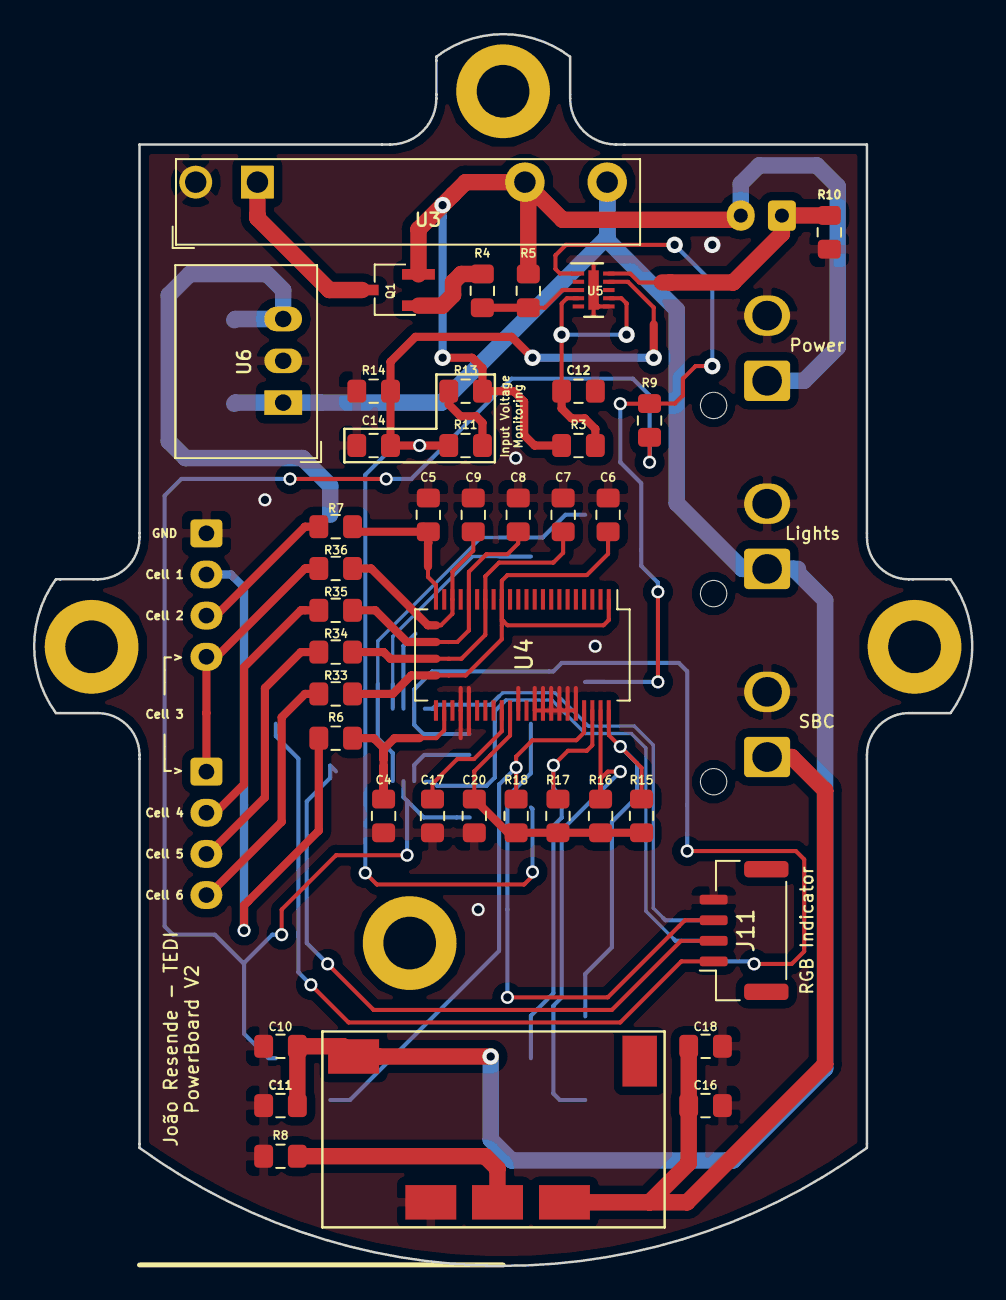
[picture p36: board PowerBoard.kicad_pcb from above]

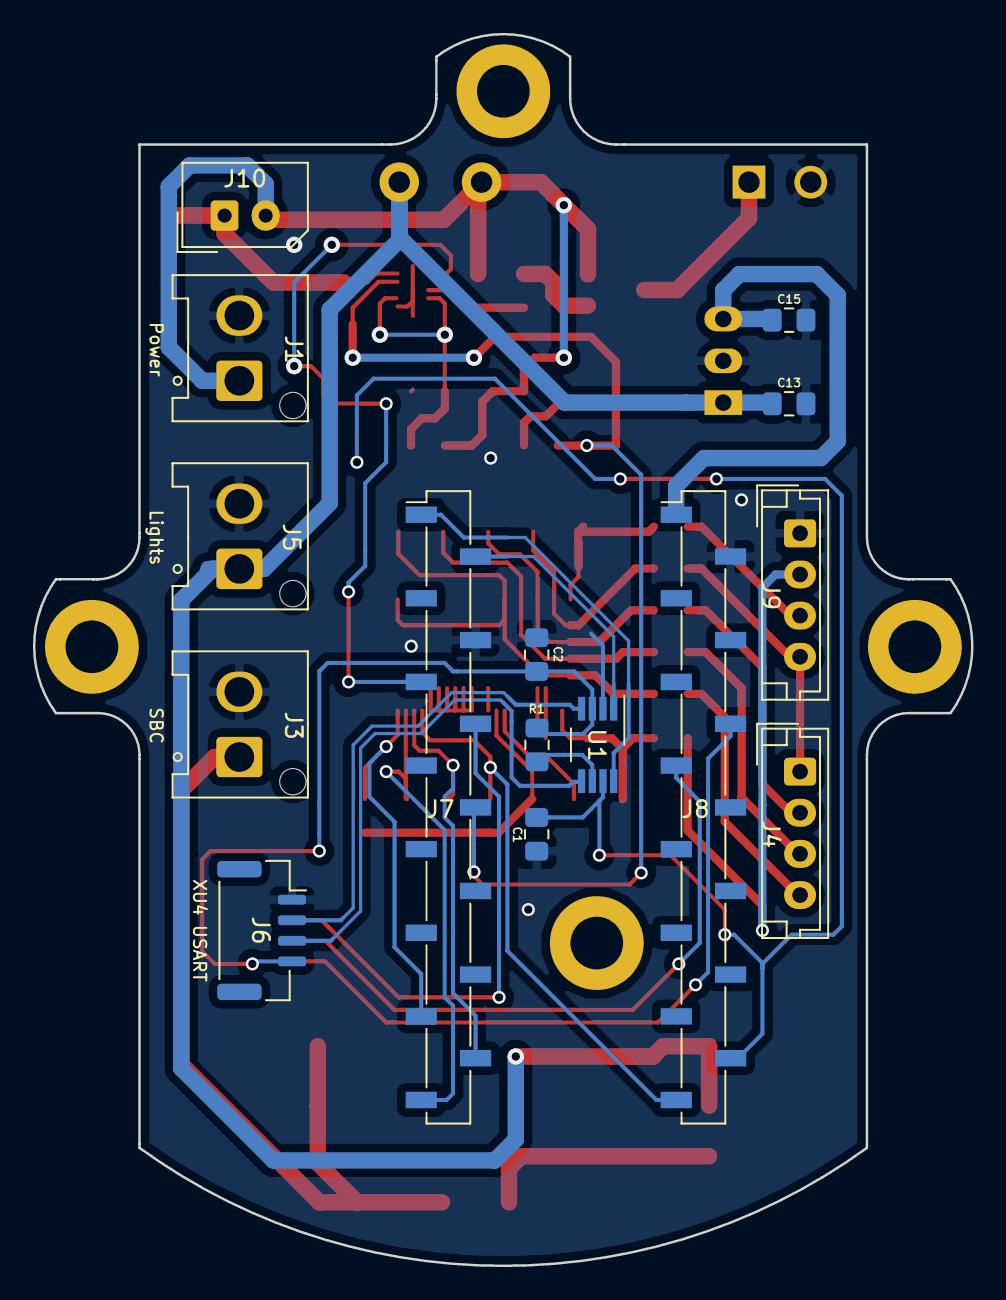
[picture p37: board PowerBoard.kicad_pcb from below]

Board: 2 copper layers, 57.0 x 74.8 mm, 55 parts (15 on the bottom side), 42 nets.

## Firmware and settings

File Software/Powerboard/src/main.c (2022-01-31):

/**
  ******************************************************************************
  * @ile    main.c
  * @author  3S0 FreeRTOs
  * @version V1.0
  * @date    24/10/2017
  * @brief   FreeRTOS Example project.
  ******************************************************************************
*/

/*
 * LASMU-BATTERY
 * Joao Resende 1140569
 * Pedro Barbosa 1140467
 * 2018-2019
 */

/* Standard includes. */
#include <string.h>
#include <stdio.h>
#include <stdlib.h>
#include <stdint.h>
#include <math.h>
#include <inttypes.h>

/* Scheduler includes. */
#include "FreeRTOS.h"
#include "task.h"
#include "semphr.h"
#include "queue.h"

/* extra includes. */
#include "USART.h"
#include "SPI.h"

/* Task priorities. */
#define mainFLASH_TASK_PRIORITY	( tskIDLE_PRIORITY + 1)
#define mainUSART_TASK_PRIORITY	( tskIDLE_PRIORITY + 1)
/***************************************/

/* Tasks delay. */
#define mainFLASH_DELAY			( ( TickType_t ) 5000 / portTICK_RATE_MS )
/***************************************/

/* Configure SETUPS */
void RCC_Config_HSI_PLL_Max( void );
static void prvSetupGPIO( void );

/***************************************/

/* Configure TASKS */
static void prvCellTask( void *pvParameters );
static void prvUSARTTask( void *pvParameters );
/***************************************/


/***************************************/

/* Tasks handle variable. */
TaskHandle_t HandleTask[3];
TaskHandle_t BlockedINFOTask;
/***************************************/

enum taskenum
{
	HandleTask1,
	HandleTask2,
	HandleTask3,
};

/***************************************/

/* Queue variable. */
QueueHandle_t xQueueUSART1_TX;
QueueHandle_t xQueueUSART1_RX;
QueueHandle_t xQueueSPI1_RX;
QueueHandle_t xQueueSPI1_TX;
/***************************************/

/* Semaphore variable. */
SemaphoreHandle_t xSemaphoreMutex_USART;
SemaphoreHandle_t xSemaphoreMutex_SPI;
SemaphoreHandle_t xSemaphoreMutex_Struct;
/***************************************/

Battery_t Battery;

/* SHUTDOWN */
#define SHUTDOWN_ON()       GPIO_ResetBits(GPIOB, GPIO_Pin_6);
#define SHUTDOWN_OFF()      GPIO_SetBits(GPIOB, GPIO_Pin_6);

int main( void )
{
	RCC_Config_HSI_PLL_Max();
	prvSetupGPIO();
	SHUTDOWN_OFF();
	prvSetupUSART(115200, 100, 1);
	prvSetupSPI();

	xSemaphoreMutex_USART = xSemaphoreCreateMutex();
	xSemaphoreMutex_Struct = xSemaphoreCreateMutex();
	/* Create the tasks */

   // xTaskCreate( prvINFOTask, 		"Clock INFO", 		configMINIMAL_STACK_SIZE+150,
   // 				NULL, mainFLASH_TASK_PRIORITY, &HandleTask[HandleTask2] );

	xTaskCreate( prvCellTask, 		"Monitoring Cells", 		configMINIMAL_STACK_SIZE+150,
	    				NULL, mainFLASH_TASK_PRIORITY+2, &HandleTask[HandleTask1] );

	xTaskCreate( prvUSARTTask, 		"Processing USART DATA", 		configMINIMAL_STACK_SIZE+150,
	      				NULL, mainFLASH_TASK_PRIORITY+1, &HandleTask[HandleTask2] );

	/* Start the scheduler. */
	vTaskStartScheduler();

	/* Will only get here if there was not enough heap space to create the idle task. */
	return 0;
}

/*-----------------------------------------------------------*/


static void prvCellTask( void *pvParameters)
{
	TickType_t xLastExecutionTime;
	xLastExecutionTime = xTaskGetTickCount();

	Battery.Battery1=0;
	Battery.Battery2=0;
	Battery.Cell[0]=0;
	Battery.Cell[1]=0;
	Battery.Cell[2]=0;
	Battery.Cell[3]=0;
	Battery.Cell[4]=0;
	Battery.Cell[5]=0;

	Battery.status[0]=0;
	Battery.status[1]=0;
	Battery.status[2]=0;
	Battery.status[3]=0;
	Battery.status[4]=0;
	Battery.ERROR_STATUS=0x00;

	write_config(); //Configuring LTC

	while(1)
	{
		vTaskDelayUntil( &xLastExecutionTime, mainFLASH_DELAY );
		start_cell_conv();
		vTaskDelay( ( ( TickType_t ) 600 / portTICK_RATE_MS ) );
		xSemaphoreTake( xSemaphoreMutex_USART, (TickType_t)portMAX_DELAY);
		read_cells(&Battery);
		xSemaphoreGive( xSemaphoreMutex_USART );

		//SHUTDOWN_ON();

		//BlockedINFOTask=xTaskGetCurrentTaskHandle();
		//vTaskSuspend(BlockedINFOTask);

	}
}
/*-----------------------------------------------------------*/

static void prvUSARTTask( void *pvParameters )
{
	//TickType_t xLastExecutionTime;
	//xLastExecutionTime = xTaskGetTickCount();

	int8_t Start = 0x10;
	int8_t pedido = 0;
	float b1, b2, bt;
	float Check_Cell[6];
	int8_t Check_Status[5]={};
	int8_t Check_Error;

	Battery.Battery1=0;
	Battery.Battery2=0;
	Battery.Cell[0]=0;
	Battery.Cell[1]=0;
	Battery.Cell[2]=0;
	Battery.Cell[3]=0;
	Battery.Cell[4]=0;
	Battery.Cell[5]=0;

	Battery.status[0]=0;
	Battery.status[1]=0;
	Battery.status[2]=0;
	Battery.status[3]=0;
	Battery.status[4]=0;
	Battery.ERROR_STATUS=0x00;

	while(1)
	{
		if( USARTGetByte()==Start) //USARTGetByte()
		{
			pedido = USARTGetByte();

			switch (pedido) //USARTGetByte()
			{
				case 0x01: //Send tension of battery's

					xSemaphoreTake( xSemaphoreMutex_Struct, (TickType_t)portMAX_DELAY);
					b1 = Battery.Battery1;
					b2 = Battery.Battery2;
					xSemaphoreGive( xSemaphoreMutex_Struct );

					bt=b1+b2;

					int8_t digit_b1 = trunc(b1);
					int8_t decimal_b1 = ( (b1*100) - digit_b1*100 );

					int8_t digit_b2 = trunc(b2);
					int8_t decimal_b2 = ( (b2*100) - digit_b2*100 );

					int8_t digit_bt = trunc(bt);
					int8_t decimal_bt = ( (bt*100) - digit_bt*100 );

					//Send Battery 1
					USARTPutByte(digit_b1); //digit of Tension
					USARTPutByte(decimal_b1); // High of decimal part
					//USARTPutByte((uint8_t) decimal_b1); //Low of decimal part

					//Send Battery 2
					USARTPutByte(digit_b2); //digit of Tension
					USARTPutByte(decimal_b2); // High of decimal part
					//USARTPutByte((uint8_t) decimal_b2); //Low of decimal part

					//Send Battery total
					USARTPutByte(digit_bt); //digit of Tension
					USARTPutByte(decimal_bt); // High of decimal part
					//USARTPutByte((uint8_t) decimal_bt); //Low of decimal part

					break;

				case 0x02: //Send tension of all Cells

					xSemaphoreTake( xSemaphoreMutex_Struct, (TickType_t)portMAX_DELAY);
					memcpy(&Check_Cell,&Battery.Cell,sizeof(Battery.Cell)); //sizeof = 5
					xSemaphoreGive( xSemaphoreMutex_Struct );

					for(int8_t i=0; i<6;i++)
					{
						uint8_t digit = trunc(Check_Cell[i]);
						uint8_t decimal = ( (Check_Cell[i]*100) - digit*100 );

						USARTPutByte(digit); //digit of Tension
						USARTPutByte(decimal); // High of decimal part
					}

					break;

				case 0x03: //Send Status of system
					xSemaphoreTake( xSemaphoreMutex_Struct, (TickType_t)portMAX_DELAY);
					memcpy(&Check_Status,&Battery.status,sizeof(Battery.status)); //sizeof = 5
					xSemaphoreGive( xSemaphoreMutex_Struct );

					for( int8_t i=0; i<6; i++)
					{
						USARTPutByte(Check_Status[i]); //Send Status of Cells 0x01 - GOOD / 0x02 - BAD / 0x03 - VERY BAD
					}

					break;

				case 0x04: //Send Errors
					xSemaphoreTake( xSemaphoreMutex_Struct, (TickType_t)portMAX_DELAY);
					Check_Error = Battery.ERROR_STATUS;
					xSemaphoreGive( xSemaphoreMutex_Struct );


					USARTPutByte(Check_Error); //Send Errors 0x00 - No Errors / 0x01 - Error Comparing PEC

					break;

				case 0x05: //Send current Configuration of LTC

					break;

				default:
						//USARTPutByte(addr);
						USARTPutByte(0xff); //erro
					break;
			}
		}

	}
}
/*-----------------------------------------------------------*/

void RCC_Config_HSI_PLL_Max( void )
{
    /* RCC configuration - 64 MHz */
    RCC_DeInit();

	/* Enable The Prefetch Buffer */
	FLASH_PrefetchBufferCmd(ENABLE);
	/* 64 MHZ - 2 wait states */
	FLASH_SetLatency(FLASH_Latency_2);

	/* No division HCLK = SYSCLK = 64 MHz*/
	RCC_HCLKConfig(RCC_SYSCLK_Div1);

	/* Use PLL with HSI = 4 MHz (4 MHz * 16 = 64 MHz) */
	RCC_PLLConfig(RCC_PLLSource_HSI_Div2, RCC_PLLMul_16);
	/* Enable the PLL */
	RCC_PLLCmd(ENABLE);
	/* Wait for PLL ready */
	while (RCC_GetFlagStatus(RCC_FLAG_PLLRDY) == RESET );

	/* Select the PLL as system clock source */
	RCC_SYSCLKConfig(RCC_SYSCLKSource_PLLCLK);
	/* Wait until PLL is used as system clock */
	while( RCC_GetSYSCLKSource() != 0x08 );
}
/*-----------------------------------------------------------*/

static void prvSetupGPIO( void )
{
    /* GPIO configuration - GREEN LED*/
    GPIO_InitTypeDef GPIO_InitStructure;

    /* Enable GPIOB clock */
    RCC_AHBPeriphClockCmd( RCC_AHBPeriph_GPIOB , ENABLE );

    GPIO_InitStructure.GPIO_Pin =  GPIO_Pin_3;
    GPIO_InitStructure.GPIO_Mode = GPIO_Mode_OUT;
    GPIO_InitStructure.GPIO_OType= GPIO_OType_PP;
    GPIO_InitStructure.GPIO_Speed = GPIO_Speed_50MHz;

    GPIO_InitStructure.GPIO_Pin =  GPIO_Pin_6;
    GPIO_InitStructure.GPIO_Mode = GPIO_Mode_OUT;
	GPIO_InitStructure.GPIO_OType= GPIO_OType_OD;
	GPIO_InitStructure.GPIO_OType= GPIO_PuPd_NOPULL;
	GPIO_InitStructure.GPIO_Speed = GPIO_Speed_50MHz;

    GPIO_Init(GPIOB, &GPIO_InitStructure);
}
/*-----------------------------------------------------------*/

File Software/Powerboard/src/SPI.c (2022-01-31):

/*
 * SPI.c
 *
 *  Created on: Jan 12, 2019
 *      Author: jfato
 */
/*
 * USART.c
 *
 *  Created on: Jan 12, 2019
 *      Author: jfato
 */

#include "SPI.h"
extern QueueHandle_t xQueueSPI1_RX;
extern QueueHandle_t xQueueSPI1_TX;

void prvSetupSPI( void )
{
	xQueueSPI1_RX = xQueueCreate( 1, sizeof(uint8_t) );
	xQueueSPI1_TX = xQueueCreate( 1, sizeof(uint8_t) );

	RCC_AHBPeriphClockCmd( RCC_AHBPeriph_GPIOA , ENABLE );
	RCC_AHBPeriphClockCmd( RCC_AHBPeriph_GPIOB , ENABLE );
	RCC_APB2PeriphClockCmd( RCC_APB2Periph_SPI1 , ENABLE );

	/* Connect MOSI & MISO & SCK pin to AF5 */
	GPIO_PinAFConfig(GPIOB, GPIO_PinSource3, GPIO_AF_5);
	GPIO_PinAFConfig(GPIOB, GPIO_PinSource4, GPIO_AF_5);
	GPIO_PinAFConfig(GPIOB, GPIO_PinSource5, GPIO_AF_5);

	/* MOSI & MISO */
	GPIO_InitTypeDef GPIO_InitStructure;
	GPIO_InitStructure.GPIO_Pin =  GPIO_Pin_4 | GPIO_Pin_5;
	GPIO_InitStructure.GPIO_Speed = GPIO_Speed_50MHz;
	GPIO_InitStructure.GPIO_Mode = GPIO_Mode_AF;
	GPIO_InitStructure.GPIO_OType = GPIO_OType_PP;
	GPIO_InitStructure.GPIO_PuPd  = GPIO_PuPd_NOPULL;
	GPIO_Init(GPIOB, &GPIO_InitStructure);

	/* SCK */
	GPIO_InitStructure.GPIO_Pin =  GPIO_Pin_3;
	GPIO_InitStructure.GPIO_Speed = GPIO_Speed_50MHz;
	GPIO_InitStructure.GPIO_Mode = GPIO_Mode_AF;
	GPIO_InitStructure.GPIO_OType = GPIO_OType_PP;
	GPIO_InitStructure.GPIO_PuPd  = GPIO_PuPd_NOPULL;
	GPIO_Init(GPIOB, &GPIO_InitStructure);

	/* CS */
	GPIO_InitStructure.GPIO_Pin = GPIO_Pin_11 ;
	GPIO_InitStructure.GPIO_Speed = GPIO_Speed_50MHz;
	GPIO_InitStructure.GPIO_Mode = GPIO_Mode_OUT;
	GPIO_Init(GPIOA, &GPIO_InitStructure);

	SPI_InitTypeDef SPI_InitStructure;
	SPI_InitStructure.SPI_Direction=SPI_Direction_2Lines_FullDuplex;
	SPI_InitStructure.SPI_Mode=SPI_Mode_Master;
	SPI_InitStructure.SPI_DataSize=SPI_DataSize_8b;
	SPI_InitStructure.SPI_CPOL=SPI_CPOL_High;
	SPI_InitStructure.SPI_CPHA=SPI_CPHA_2Edge;
	SPI_InitStructure.SPI_NSS=SPI_NSS_Soft;
	SPI_InitStructure.SPI_BaudRatePrescaler = SPI_BaudRatePrescaler_128; // 0.5MHz
	SPI_InitStructure.SPI_FirstBit = SPI_FirstBit_MSB;

	SPI_Init(SPI1, &SPI_InitStructure);

	SPI_I2S_ITConfig(SPI1, SPI_I2S_IT_RXNE, ENABLE);
	SPI_RxFIFOThresholdConfig(SPI1,SPI_RxFIFOThreshold_QF);

	NVIC_InitTypeDef NVIC_InitStructure;
	NVIC_PriorityGroupConfig(NVIC_PriorityGroup_1);
	NVIC_InitStructure.NVIC_IRQChannel = SPI1_IRQn;
	NVIC_InitStructure.NVIC_IRQChannelPreemptionPriority = 1;
	NVIC_InitStructure.NVIC_IRQChannelSubPriority = 2;
	NVIC_InitStructure.NVIC_IRQChannelCmd = ENABLE;

	NVIC_Init(&NVIC_InitStructure);

	SPI_Cmd(SPI1, ENABLE);
}


uint8_t SPIPutGetByte(uint8_t TxData)
{
	if( xQueueSPI1_TX != 0 )
	{
		xQueueSendToBack( xQueueSPI1_TX, &TxData, ( TickType_t ) 100 );
		SPI_I2S_ITConfig(SPI1, SPI_I2S_IT_TXE, ENABLE);
	}

	if( xQueueSPI1_RX != 0 )
	{
		uint8_t RxData;
		xQueueReceive( xQueueSPI1_RX, &RxData, ( TickType_t ) 100 );
		return RxData;
	}
	return 0;
}


void SPIClose(void)
{
	SPI_I2S_DeInit(SPI1);
	SPI_I2S_ITConfig(SPI1, SPI_I2S_IT_TXE, DISABLE);
	SPI_I2S_ITConfig(SPI1, SPI_I2S_IT_RXNE, DISABLE);
	vQueueDelete(xQueueSPI1_RX);
	vQueueDelete(xQueueSPI1_TX);
}

void start_cell_conv ()
{
	uint8_t PEC;
	uint8_t byte;

	CS_Low();

	byte=0x80;//Address
	PEC = computePEC(byte,0x41);
	SPIPutGetByte(byte);
	SPIPutGetByte(PEC);

	byte=0x10; //PLINT
	PEC = computePEC(byte,0x41);
	SPIPutGetByte(byte);
	SPIPutGetByte(PEC);

	CS_High();
}

int8_t read_cells(Battery_t *Battery)
{

	char rx_buffer[18];
	char PEC;
	char byte;

	CS_Low(); //Pull CSBI low

	byte=0x80; //Send Address and PEC byte for bottom device
	PEC = computePEC(byte,0x41);
	SPIPutGetByte(byte);
	SPIPutGetByte(PEC);

	byte=0x04; //Send RDCV command and its PEC byte
	PEC = computePEC(byte,0x41);
	SPIPutGetByte(byte);
	SPIPutGetByte(PEC); //PEC

	for(int i=0; i<18; i++)//Read CVR00 byte of bottom device, then CVR01 (B), CVR02 (B), … CVR17 (B), and then PEC (B)
	{
		rx_buffer[i]= SPIPutGetByte(0x00); //CVRxx [0-17]
		PEC = computePEC(rx_buffer[i],PEC);

		/*sprintf(buffer,"Read bytes %i 0x%x\r\n" , i , buffer[i]);
	    USARTPutString(buffer,strlen(buffer));*/
	}

	char PEC_received=SPIPutGetByte(0x00);

	//Check PEC received from CVR00 to CVR17

	//if( PEC != PEC_received)
	//{
		//Battery->ERROR_STATUS=0x01;
		//return 0;
	//}

	CS_High(); //Pull CSBI high

	//CALCULATE VOLTAGE
	uint8_t reg = 0;
	uint16_t low, high;
	uint16_t cellADC12bits[9];

	for (int k = 0; k<12; k+=2) //from CVR00 until CVR11 (8cells)
	{
		low = (uint16_t)rx_buffer[reg];
		reg++;
		high = (uint16_t)(rx_buffer[reg]&0x0F)<<8;
		cellADC12bits[k] = low + high;

		high = (uint16_t)(rx_buffer[reg]&0xF0)>>4;
		reg++;
		low = (rx_buffer[reg])<<4;
		cellADC12bits[k+1] = low + high;

		reg++;
	}

	//Calculating and checking Cell Status for LiPO
	for ( int8_t i=0; i<6; i++)
	{
		Battery->Cell[i]= ((float)cellADC12bits[i] - 512)*0.0015;

		if( Battery->Cell[i] < 3.5  ){
			Battery->status[i] = 0x02;
		}else if( Battery->Cell[i] < 3.1  ){ //VERIFICAR
			Battery->status[i] = 0x03; //SHUTDOWN
		}
		else{
			Battery->status[i] = 0x01;
		}
	}

	//Calculating Battery 1 and 2 Tension
	Battery->Battery1 = Battery->Cell[0] + Battery->Cell[1] + Battery->Cell[2];
	Battery->Battery2 = Battery->Cell[3] + Battery->Cell[4] + Battery->Cell[5];

	return 1;
}

void write_config ()
{
	uint8_t PEC;
	uint8_t byte;

	CS_Low();

	byte=0x80; //Address
	PEC = computePEC(byte,0x41);
	SPIPutGetByte(byte);
	SPIPutGetByte(PEC);

	byte=0x01; //WRCFG command
	PEC = computePEC(byte,0x41);
	SPIPutGetByte(byte);
	SPIPutGetByte(PEC);

	byte=0x11; //CFGR0 byte
	PEC = computePEC(byte,0x41);
	SPIPutGetByte(byte);

	byte=0x00; //CFGR1 byte
	PEC = computePEC(byte,PEC);
	SPIPutGetByte(byte);

	byte=0xF0; //CFGR2 byte
	PEC = computePEC(byte,PEC);
	SPIPutGetByte(byte);

	byte=0xFF; //CFGR3 byte
	PEC = computePEC(byte,PEC);
	SPIPutGetByte(byte);

	byte=0x00; //CFGR4 byte
	PEC = computePEC(byte,PEC);
	SPIPutGetByte(byte);

	byte=0x00; //CFGR5 byte
	PEC = computePEC(byte,PEC);
	SPIPutGetByte(byte);
	SPIPutGetByte(PEC);

	CS_High();
}

void read_config ()
{
	char buffer[50];

	char rx_buffer[7];
	uint8_t PEC;
	uint8_t byte;

	sprintf(buffer,"Reading LTC6803 Config \n\r");
	USARTPutString(buffer,strlen(buffer));

	CS_Low();

	byte=0x80; //Address
	PEC = computePEC(byte,0x41);
	SPIPutGetByte(byte);
	SPIPutGetByte(PEC);

	byte=0x02; //RDCFG command
	PEC = computePEC(byte,0x41);
	SPIPutGetByte(byte);
	SPIPutGetByte(PEC);

	for(int i=0; i<7; i++)//CFGRx[0-5]+PEC
	{
		rx_buffer[i] = SPIPutGetByte(0x00); //CFGRx [0-5]
		PEC = computePEC(rx_buffer[i],PEC);

		//sprintf(buffer,"Read bytes %i 0x%x\r\n" , i , rx_buffer[i]);
	    //USARTPutString(buffer,strlen(buffer));
	}

	for(int i=0; i<7; i++)//CFGRx[0-5]+PEC
	{
		//sprintf(buffer,"Read bytes %i 0x%x\r\n" , i , rx_buffer[i]);
		//USARTPutString(buffer,strlen(buffer));
	}
	CS_High();
}
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

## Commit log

2022-01-28 added 3D drawings of the mechanical parts
    [COMPOUND.sldprt, COMPOUND_3.sldprt, DTCM230-36.SLDPRT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]
2022-01-30 added powerboard project
    [PowerBoard.STL, PowerBoard.kicad_pcb, PowerBoard.sch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]
2022-01-31 added 3D animation of the Powerboard
2022-01-31 added Powerboard software (STM32F303K8)
    [FreeRTOS_STM32F303K8 Run.cfg]
2022-01-31 added illumination board
    [022057045.stp, Ligths.kicad_pcb, Ligths.sch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]
